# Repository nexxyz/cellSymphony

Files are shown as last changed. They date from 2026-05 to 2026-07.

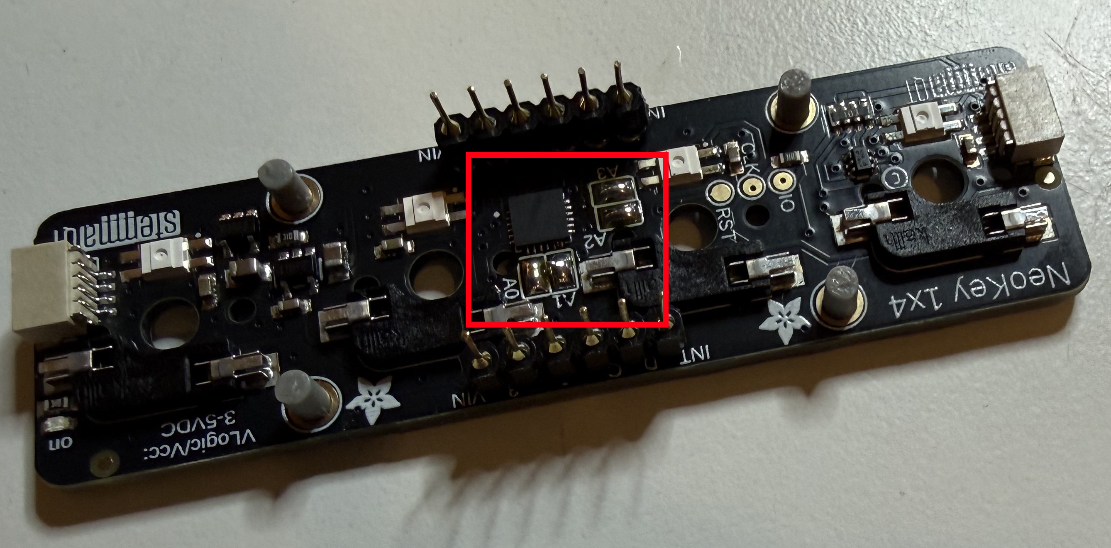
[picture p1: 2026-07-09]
userdocs/hardware/images/assembly/neokey-address-jumpers.jpg

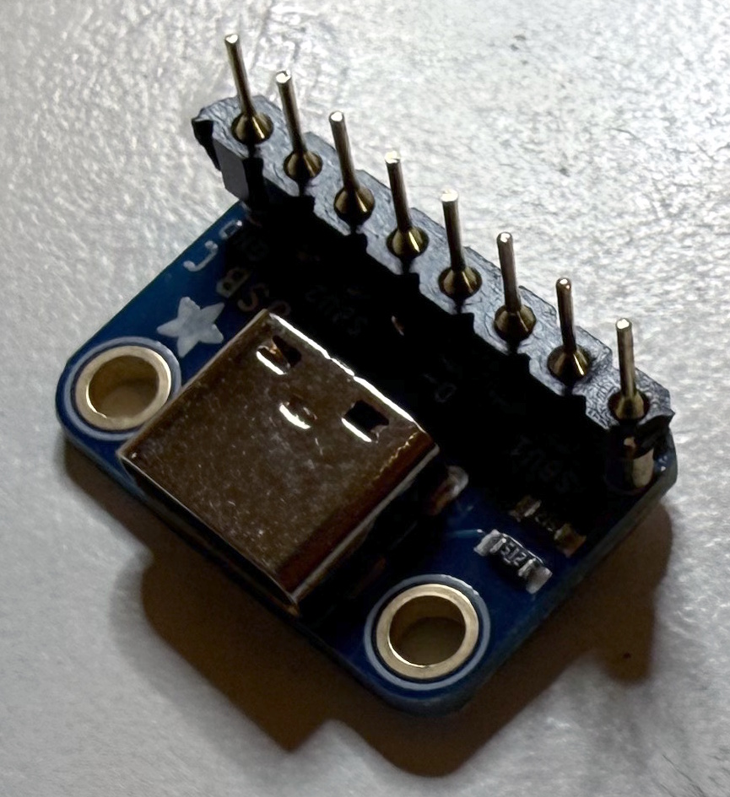
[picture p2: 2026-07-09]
userdocs/hardware/images/assembly/power-breakout.jpg

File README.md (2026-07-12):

# octessera

Octessera turns cellular automata into music you can play.

It is a collection of little algorithmic musical world-bubbles: small systems you set up, nudge, combine, and occasionally interrupt. You are not programming fixed notes on a piano roll. You are giving tiny rule-based worlds something to do, adding a bit of manual sequencing when you want an anchor, and then playing the result in real time.

Start with the user docs: [`userdocs/README.md`](userdocs/README.md).

Create a dynamic, evolving beat in minutes. Let Conway's Life generate a shifting synth backdrop. Add a drumbeat with a classic grid-style sequencer. Make the drums duck the synth out of the way. Play a lead line live. Then jump into Sparks mode and perform with live effects, change trigger probability, and use the XY pad and mixer controls to build something that you and octessera found together.

It is easy to start with, but deep. It rewards exploration and experimentation. Small changes to the grid can become rhythms, melodies, modulation, texture, or surprise.

The intended way of using it is a DIY standalone hardware instrument based on a Raspberry Pi. There is, however, a fully implemented desktop app that serves simulator for building, testing, and playing the same instrument on a computer - but it is also quite usable and effective, if you don't want another piece of gear to clutter your valuable desk real estate.

## What You Can Make

- **Generative synth patterns** from Life, Brain, Ant, Bounce, Raindrops, DLA, and other grid behaviors.
- **Hands-on drum patterns** with a sequencer-style grid and sample slots.
- **Layered arrangements** with up to eight layers/instruments.
- **Live leads** with the Keys behavior.
- **Evolving modulation** where grid motion changes pitch, filter, velocity, effects, and other parameters.
- **Internal synth and sampler sounds**, plus external MIDI output.
- **Performance scenes** with Play pages: mix, pan, trigger probability, XY modulation, and momentary effects.
- **Happy accidents** from systems that keep moving after you set them in motion.

## A Quick Session

1. Pick a layer in **Build** and choose a behavior such as `life`, `brain`, or `raindrops`.
2. Draw or seed a few cells on the grid.
3. Press **Space** to start playback.
4. Go to **Shape** and choose a synth, sampler or even MIDI output for the layer.
5. Add a sequencer layer for drums, have it play a sampler with your preferred drum samples (we even provide a small sample library for you!)
6. Then route the synth through an FX bus with ducking so the beat opens space in the mix.
7. Switch another layer to **Keys** and play a lead line live.
8. Hold **Fn** for navigation and use the right grid column to enter **Play** pages.
9. Perform: mute, pan, change probability, move XY controls, and punch in live effects.

You can treat it like a algorithmic groovebox, a generative sketchpad, or a small experimental performance instrument.

## Controls

The hardware (still under design) uses one clickable main encoder, three clickable aux encoders, four keys with LEDs, an 8x8 grid and a small OLED. The desktop simulator mirrors those controls with keyboard and UI inputs.

| Action | Hardware | Desktop |
|---|---|---|
| Move or change a value | Main encoder turn | Arrow keys |
| Enter, edit, or confirm | Main encoder press | Enter |
| Back or leave edit mode | Back button | Backspace / Esc |
| Play / pause | Space button | Space |
| Emergency stop | Shift + Space | Shift + Space |
| Clear active grid | Shift + Back | Shift + Backspace / Shift + Esc |
| Navigate layers | Fn + left grid column | Ctrl + left grid column |
| Navigate Play pages | Fn + right grid column | Ctrl + right grid column |
| Access alternate aux binding | Fn + aux press | Fn + aux UI control |

The friendly control guide starts at [`userdocs/controls-cheat-sheet.md`](userdocs/controls-cheat-sheet.md). The canonical control/menu spec is [`docs/menu-and-controls-spec.md`](docs/menu-and-controls-spec.md).

## Main Pages

- **Build** — choose the active layer's behavior and edit its grid state.
- **Link** — decide how grid motion becomes notes, velocity, filters, probability, and modulation.
- **Shape** — choose synth, sampler, MIDI, mixer routing, FX buses, and global FX.
- **Play** — perform with mix, pan, trigger probability, XY, and momentary effects.
- **System** — presets, default/factory actions, sound, MIDI, brightness, sleep, and help.

## Build The Hardware

The intended build is a DIY standalone instrument around a custom PCB, Raspberry Pi Zero 2 W, NeoTrellis grid, NeoKey controls, OLED, DAC, and printed enclosure.

Start with the full assembly guide:

- [`userdocs/hardware/assembly-manual.md`](userdocs/hardware/assembly-manual.md) — BOM, PCB ordering, soldering, module setup, Pi flashing, first power-on, and enclosure assembly.

Related references:

1. [`userdocs/hardware/pinout-and-connections.md`](userdocs/hardware/pinout-and-connections.md) — wiring, pin ownership, buses, and hardware source of truth.
2. [`userdocs/hardware/enclosure.md`](userdocs/hardware/enclosure.md) — case, port access, print notes, and power rule.
3. [`docs/menu-and-controls-spec.md`](docs/menu-and-controls-spec.md) — runtime controls, menus, overlays, and display behavior.

## Desktop Simulator

The easiest way to play with this system is to download and launch the portable Windows EXE attached to the official releases.

Releases may also include macOS and Linux desktop simulator builds. Those are currently untested; treat them as experimental until someone has done the boring part and actually run them on those systems.

It allows you try out Octessera without any special hardware.

## Documentation Map

Primary user docs:

- [`userdocs/README.md`](userdocs/README.md): start here for build, bring-up, controls, printable sheets, and references.
- [`userdocs/hardware/assembly-manual.md`](userdocs/hardware/assembly-manual.md): hardware BOM, soldering, first power-on, and enclosure assembly.
- [`userdocs/hardware/pinout-and-connections.md`](userdocs/hardware/pinout-and-connections.md): Pi wiring, bus allocation, logical input mapping, and hardware source of truth.
- [`userdocs/hardware/enclosure.md`](userdocs/hardware/enclosure.md): enclosure ports, power rule, printing notes, and mechanical strategy.
- [`userdocs/controls-cheat-sheet.md`](userdocs/controls-cheat-sheet.md): hardware and simulator controls.
- [`userdocs/behaviors-and-sparks.md`](userdocs/behaviors-and-sparks.md): behavior overview and Sparks page reference.
- [`userdocs/print/quick-reference.pdf`](userdocs/print/quick-reference.pdf): two-page printable controls, behaviors, Sparks, and signal-flow sheet.

Canonical specs:

- [`docs/menu-and-controls-spec.md`](docs/menu-and-controls-spec.md): authoritative controls, menu structure, overlays, persistence, and display behavior.
- [`docs/menu-tree-spec.md`](docs/menu-tree-spec.md): canonical menu tree.

Secondary contributor docs:

- [`docs/runtime-boundaries.md`](docs/runtime-boundaries.md): crate/host responsibilities and dependency boundaries.
- [`docs/development-workflows.md`](docs/development-workflows.md): current development, build, verification, and capability-generation commands.
- [`docs/engineering-quality-requirements.md`](docs/engineering-quality-requirements.md): current quality gates and definition of done.
- [`docs/open-work.md`](docs/open-work.md): current actionable work only.

## Samples

Repository sample content is sourced from the [Stargate sample pack](https://github.com/stargatedaw/stargate-sample-pack).

## Hardware model attributions

The standoff STL models in `release-artifacts/enclosure/` are based on [Stackable PCB Standoff by theduckom](https://www.printables.com/model/163087-stackable-pcb-standoff), licensed under [Creative Commons Attribution 4.0 International](https://creativecommons.org/licenses/by/4.0/).

AI assistance was used during the creation of Octessera.

## License

Copyright (c) 2026 nexxyz.

Free for personal/non-commercial use: you may use, copy, modify, and build this software for personal purposes.

Commercial use or selling hardware devices requires prior written permission.

To request permission, contact: https://github.com/nexxyz

See [LICENSE](LICENSE) for full terms.

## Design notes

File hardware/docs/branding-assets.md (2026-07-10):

# Branding assets

This project uses the octessera mark and wordmark across hardware docs, PCB silkscreen, enclosure CAD, Pi splash screens, Raspberry Pi Imager metadata, and the desktop hardware simulator icon.

## Source assets

- `assets/octessera-mark.svg`: vector mark source.
- `assets/octessera-wordmark.svg`: grid-native vector wordmark source.
- `tools/assets/generate_pi_logo_pngs.py`: generates Pi splash and Imager PNG assets.
- `apps/desktop/src-tauri/icons/`: generated desktop simulator icon assets.
- `hardware/enclosure/branding_marking_cadquery.py`: converts the SVG mark and wordmark into CadQuery solids.
- `hardware/pcb/octessera.kicad_pcb`: contains the PCB silkscreen branding geometry.

Keep the SVGs as the source of truth. Do not hand-edit generated PNGs, STL files, STEP files, or 3MF files as source.

## Fill rules

The wordmark SVG is built from filled block paths. When rasterizing or converting it, use union-fill semantics: a point is filled if it is inside any wordmark path.

Do not use even-odd/parity fill for the current wordmark. Even-odd fill can cancel overlapping or touching block paths and can remove letter joins.

If a future wordmark uses compound paths with holes, update the source model explicitly instead of silently changing all converters to parity fill.

## Pi PNGs and initramfs

Run this after changing the mark or wordmark SVG:

```powershell
python tools/assets/generate_pi_logo_pngs.py
```

Generated PNGs:

- `assets/octessera-pi-manifest.png`: Raspberry Pi Imager icon.
- `assets/octessera-app-large.png`: desktop app icon source.
- `assets/octessera-pi-booting.png`: Pi boot splash.
- `assets/octessera-pi-sleeping.png`: sleep splash mark.
- `assets/octessera-pi-shutdown.png`: shutdown splash mark.
- `apps/desktop/src-tauri/icons/icon.png`: desktop hardware simulator icon.
- `apps/desktop/src-tauri/icons/icon.ico`: Windows desktop hardware simulator icon.

The Pi build embeds the PNGs through `apps/pi-zero/build.rs`, which writes RGB565 splash assets into Cargo `OUT_DIR`. Rebuild the Pi binary or Pi image/initramfs after changing these PNGs.

## Enclosure branding

The enclosure top uses `hardware/enclosure/branding_marking_cadquery.py`.

- STEP/STL exports keep branding as raised separate solids.
- The branded multicolor 3MF keeps the branding flush with the top surface and assigns it to extruder 2.

Use the branded top wrapper after changing branding or top enclosure CAD:

```powershell
powershell -NoProfile -ExecutionPolicy Bypass -File hardware/enclosure/generate_branded_top_artifacts_checked.ps1
```

Expected outputs:

- `release-artifacts/enclosure/step/case_top_two_level_cadquery.step`
- `release-artifacts/enclosure/stl/case_top_two_level_cadquery.stl`
- `release-artifacts/enclosure/3mf-multicolor/case_top_two_level_multicolor.3mf`
- ignored review images under `hardware/enclosure/review/`

Do not restore the old unbranded top 3MF; the top 3MF should be multicolor only.

## PCB branding

The PCB silkscreen branding lives in `hardware/pcb/octessera.kicad_pcb` on `F.SilkS`.

Use `assets/octessera-mark.svg` and `assets/octessera-wordmark.svg` as the basis when regenerating it. Preserve the manually tuned placement unless intentionally changing the PCB layout.

After editing generated PCB graphic primitives, check:

- parentheses are balanced;
- UUIDs are unique;
- no local absolute paths are introduced;
- `by nexxyz` remains present if the layout still uses the byline.

## Cleanup checklist

Before committing branding or hardware artifact changes, check:

- no local Windows absolute paths in tracked project files;
- KiCad libraries live under `hardware/pcb/kicad-libs/`;
- review images are under ignored `hardware/enclosure/review/`, not `release-artifacts/`;
- the old unbranded top 3MF is absent;
- generated Python `__pycache__/` directories are not staged;
- `git diff --check` passes.

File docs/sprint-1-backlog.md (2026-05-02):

# Sprint 1 Backlog (Foundation + Simulator Skeleton)

## Sprint Goal

Establish the modular foundation and desktop simulator skeleton with strict hardware-style controls, while keeping platform/navigation/transport decoupled from generative behavior logic.

## Deliverables

- Monorepo skeleton and package boundaries
- Device contracts and event schemas
- Platform core scaffolding (navigation + transport interfaces)
- Behavior API and Game of Life behavior module scaffold
- Desktop simulator shell with required keyboard/control mappings
- CI workflow scaffold and quality gates in repository

## Backlog Items

### 1) Repository Skeleton

Priority: High

Tasks:

- Create directories:
  - `apps/desktop`
  - `packages/device-contracts`
  - `packages/platform-core`
  - `packages/behavior-api`
  - `packages/behaviors-life`
  - `packages/musical-events`
  - `crates/realtime-engine`
- Add top-level workspace manifests (`pnpm-workspace.yaml`, root `package.json`).
- Add base TypeScript config and shared lint/format config.

Acceptance:

- Workspace install and base scripts resolve cleanly.

### 2) Device Contract Definitions

Priority: High

Tasks:

- Add TS types for device input:
  - `EncoderTurn`, `EncoderPress`, `ButtonA`, `ButtonS`, `GridPress`
- Add TS types for render/output models:
  - `DisplayFrame`, `LedMatrixFrame`, `TransportFrame`, `EngineFrame`
- Add serialization-safe schemas (zod or equivalent) for project storage boundaries.

Acceptance:

- Contract package builds and exports typed public API.

### 3) Platform Core Scaffolding

Priority: High

Tasks:

- Implement navigation state machine skeleton:
  - page selection
  - focus/edit mode
  - Back/Cancel handling (Button A)
- Implement transport state skeleton:
  - play/stop toggle (Button S)
  - bpm value storage
  - clock interface abstraction (implementation deferred)
- Define behavior host interface:
  - register active behavior
  - route input/tick
  - collect `MusicalEvent` output

Acceptance:

- Platform core handles controls without referencing any specific behavior internals.

### 4) Behavior API + Game of Life Module Scaffold

Priority: High

Tasks:

- Create behavior API package with interface/lifecycle contracts.
- Create `behaviors-life` package implementing the interface with placeholders.
- Add deterministic state/tick scaffolding and serialization stubs.

Acceptance:

- Platform can mount behavior module via API without direct imports into UI layer.

### 5) Desktop Simulator UI Skeleton

Priority: High

Tasks:

- Initialize Tauri + React app shell.
- Build required UI elements:
  - screen panel
  - encoder control widget
  - A/S button widgets
  - clickable 8x8 matrix
- Implement keyboard mapping:
  - Left/Right -> encoder delta
  - Enter -> encoder press
  - A/S -> dedicated buttons
- Route events through contract bus only.

Acceptance:

- Visible simulator shell operates with required mappings and emits typed input events.

### 6) CI + Quality Baseline Integration

Priority: High

Tasks:

- Add CI workflow (`.github/workflows/ci.yml`) and adjust scripts as packages land.
- Add minimal test harness in TS packages.
- Add rust crate skeleton with passing fmt/clippy/test commands.

Acceptance:

- CI passes for scaffold state on PR.

## Suggested Task Order

1. Repository skeleton
2. Device contracts
3. Platform core scaffold
4. Behavior API + life scaffold
5. Desktop simulator skeleton
6. CI script wiring and test harness

## Out of Scope for Sprint 1

- Full CA musical mapping logic
- MIDI runtime implementation
- Internal synth DSP implementation
- FLAC import conversion pipeline implementation
- ROMpler playback engine implementation

## Risks and Mitigation

- Risk: accidental coupling between UI and behavior internals.
  - Mitigation: enforce contract-only data flow in code reviews/tests.
- Risk: CI workflow mismatch before scripts exist.
  - Mitigation: include temporary no-op or scaffold scripts and tighten quickly.

## Definition of Done (Sprint 1)

- All Sprint 1 deliverables are merged with passing CI.
- Control mappings match the hardware-first specification.
- Platform/navigation/transport code remains behavior-agnostic.
- A behavior module can be swapped without touching platform core interfaces.

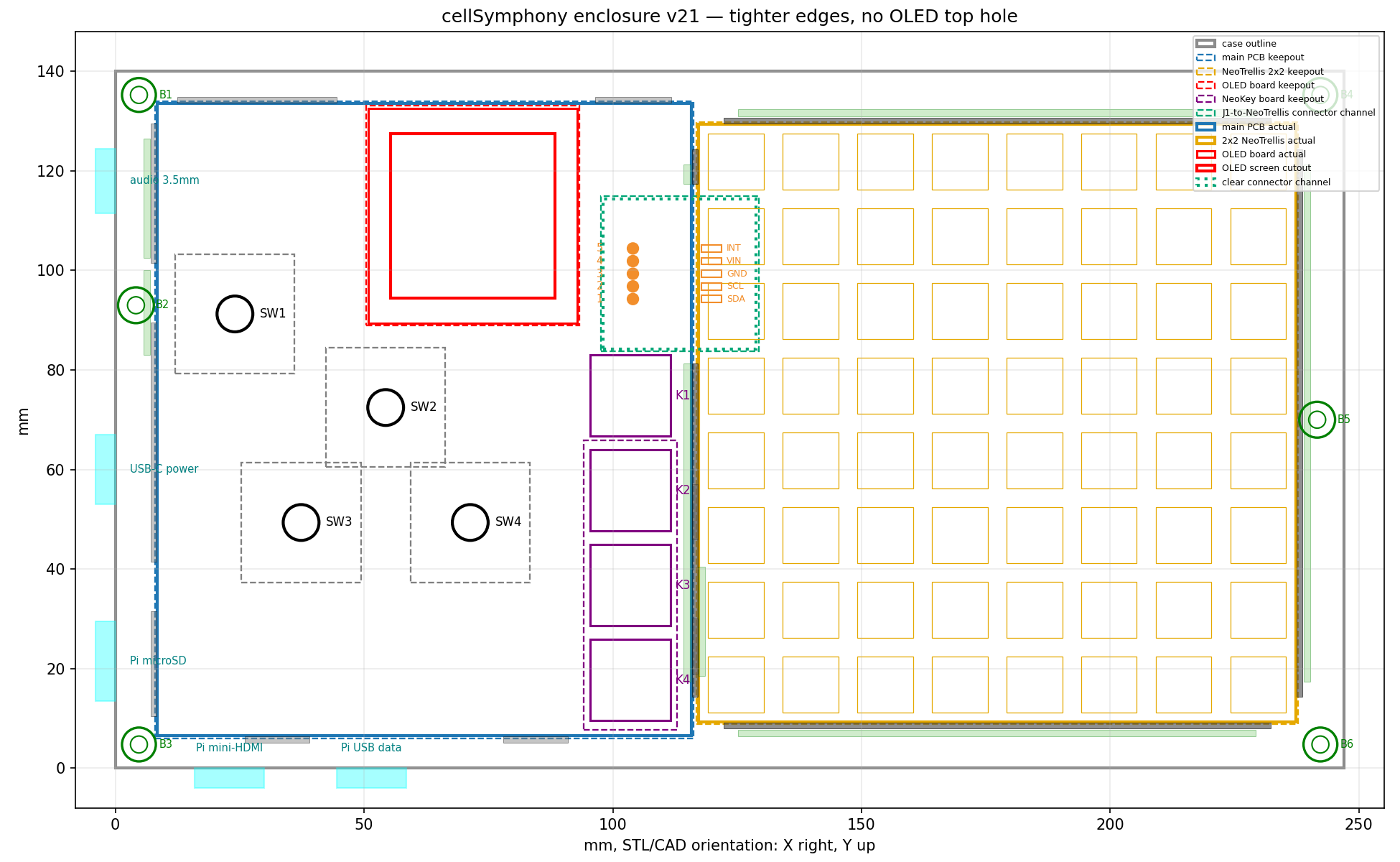
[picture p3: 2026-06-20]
hardware/enclosure/layout.png

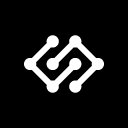
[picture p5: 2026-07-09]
assets/octessera-pi-shutdown.png

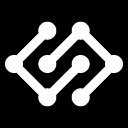
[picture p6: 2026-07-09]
assets/octessera-app-large.png

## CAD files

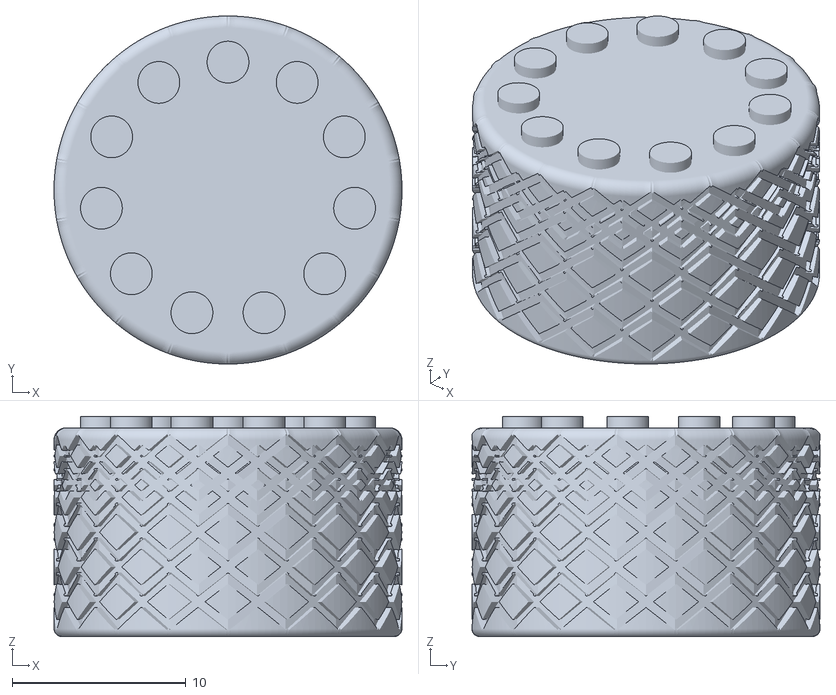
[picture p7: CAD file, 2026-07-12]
release-artifacts/enclosure/stl/encoder_cap_main_knurled_dots.stl
20.0 x 20.0 x 12.6

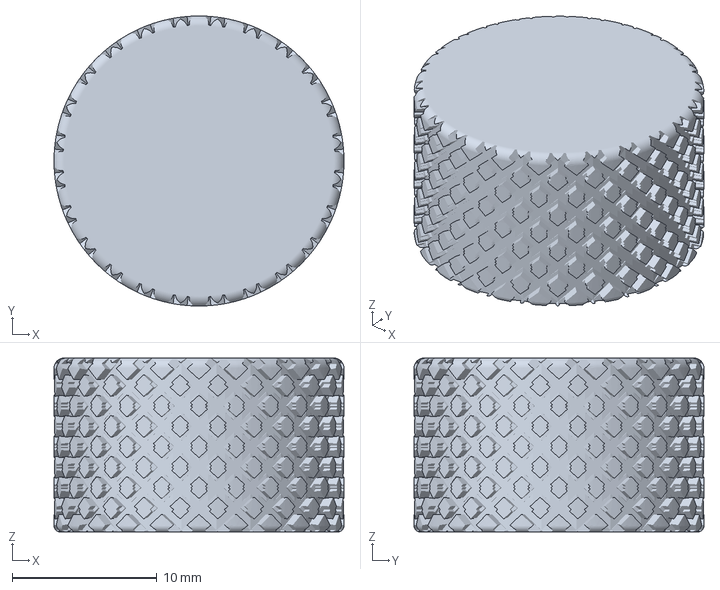
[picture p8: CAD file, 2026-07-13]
release-artifacts/enclosure/3mf-multicolor/encoder_cap_main_knurled_dots_multicolor_flush.3mf
20.0 x 20.0 x 12.0 mm

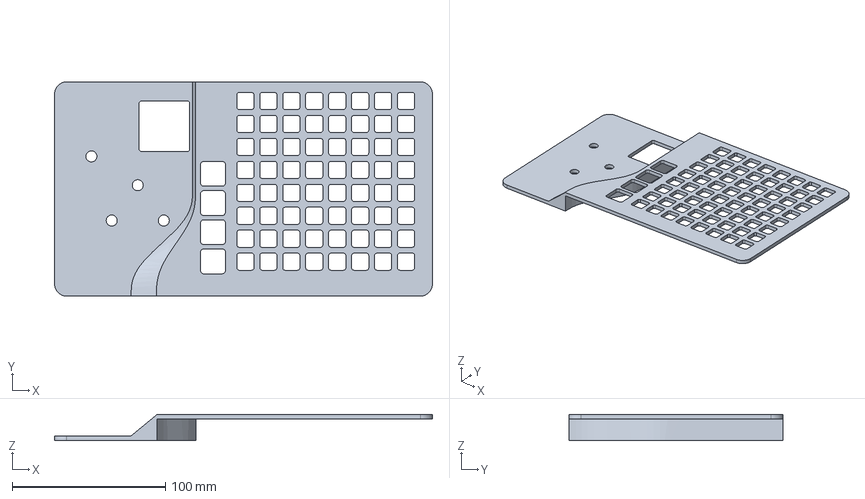
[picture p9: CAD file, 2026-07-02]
hardware/enclosure/case_top_two_level_cadquery.step
247.0 x 140.0 x 17.0 mm

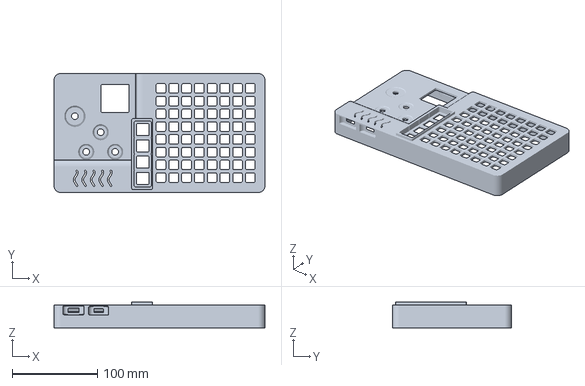
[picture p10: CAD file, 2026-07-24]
release-artifacts/enclosure/3mf-multicolor/case_top_two_level_multicolor.3mf
248.0 x 140.0 x 30.0 mm

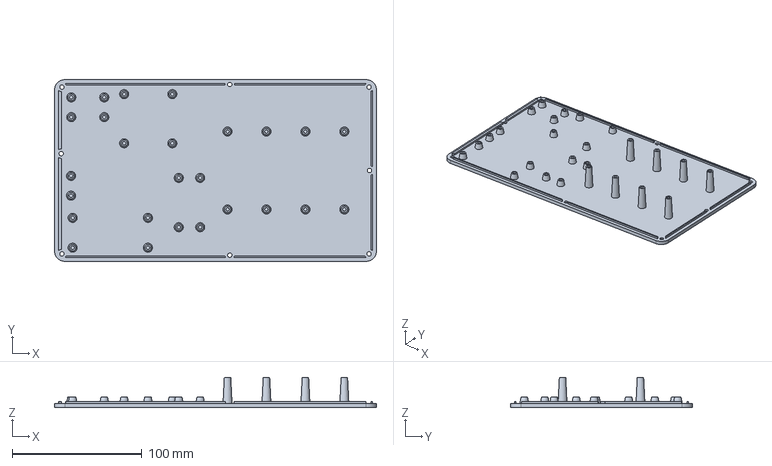
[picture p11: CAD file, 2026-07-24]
release-artifacts/enclosure/step/case_bottom_plate_cadquery.step
248.0 x 140.0 x 23.2 mm

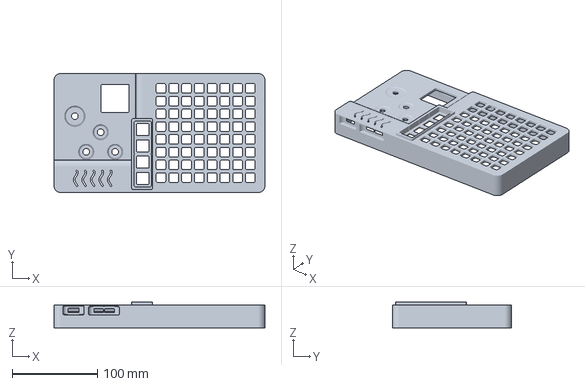
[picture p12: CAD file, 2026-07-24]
release-artifacts/enclosure/3mf-multicolor/case_top_two_level_orange_pi_multicolor.3mf
248.0 x 140.0 x 30.0 mm

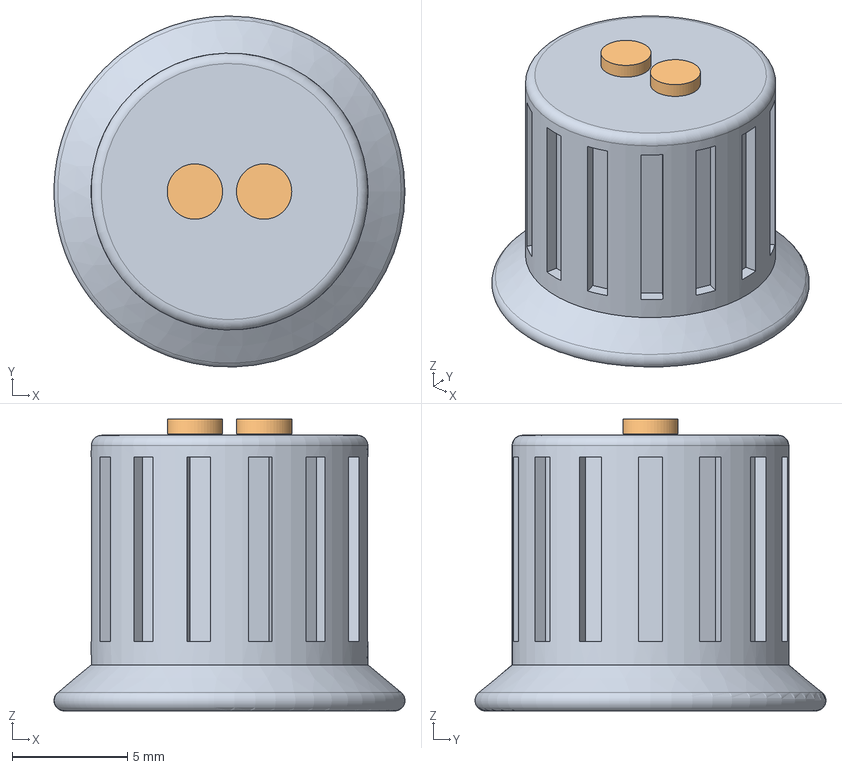
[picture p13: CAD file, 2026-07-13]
release-artifacts/enclosure/step/encoder_cap_aux2_ribbed_dots.step
15.2 x 15.2 x 12.7 mm

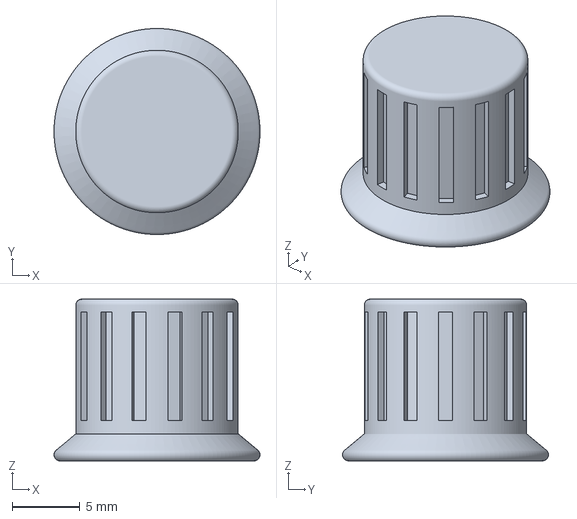
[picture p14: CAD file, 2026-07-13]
release-artifacts/enclosure/3mf-multicolor/encoder_cap_aux1_ribbed_dot_multicolor_flush.3mf
15.2 x 15.2 x 11.9 mm

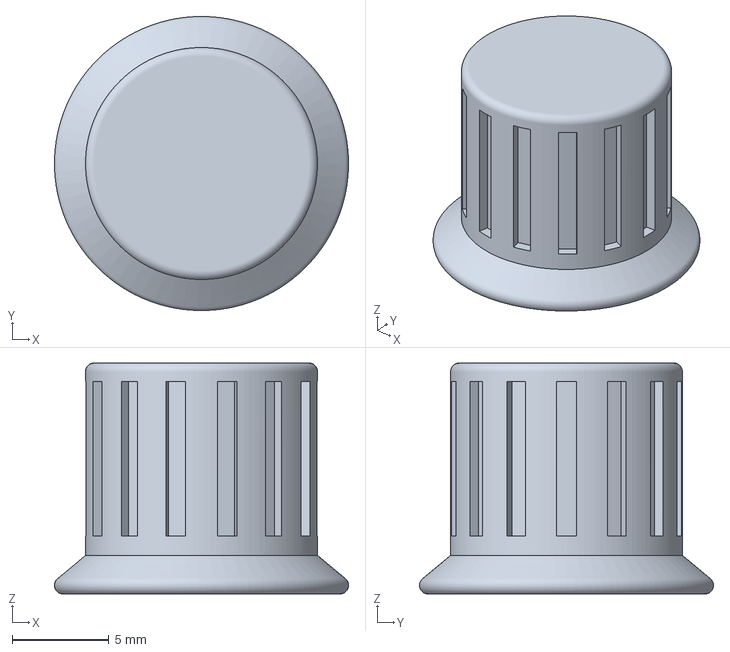
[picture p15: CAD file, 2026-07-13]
release-artifacts/enclosure/3mf-multicolor/encoder_cap_aux3_ribbed_dots_multicolor_flush.3mf
15.2 x 15.2 x 11.9 mm

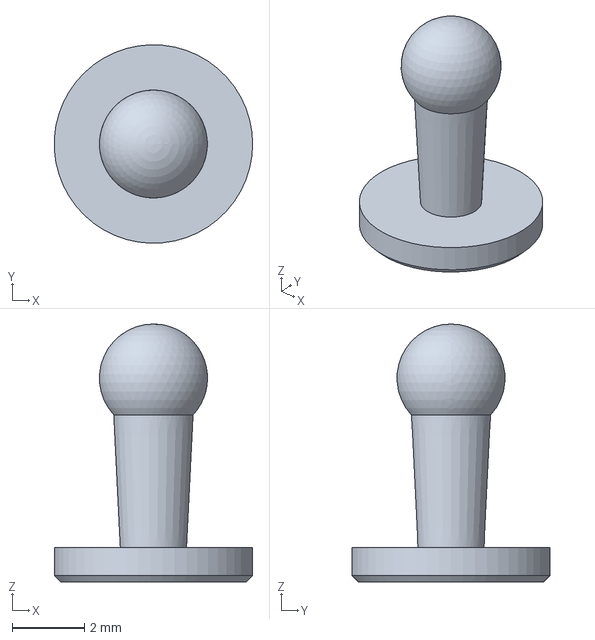
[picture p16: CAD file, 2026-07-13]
release-artifacts/enclosure/step/friction_insert_spreading_pin_headed.step
5.49 x 5.50 x 7.15 mm

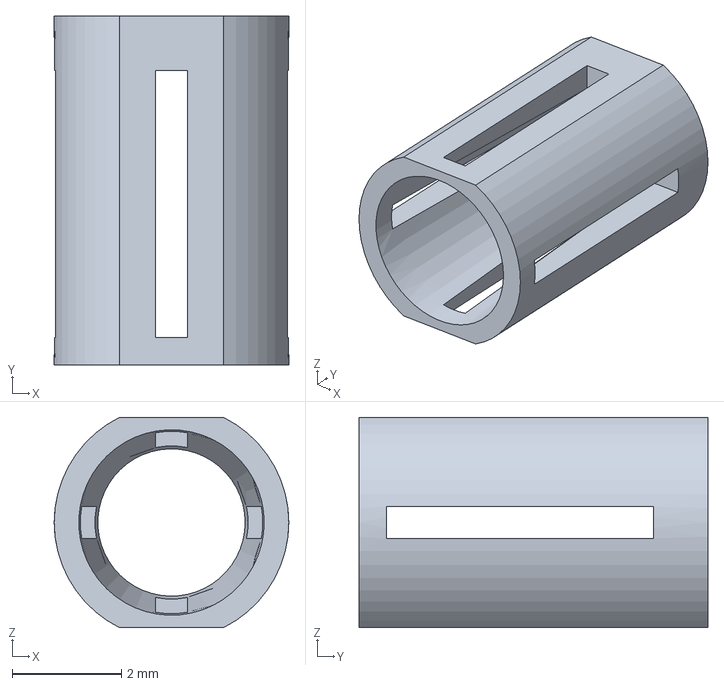
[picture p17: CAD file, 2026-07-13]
release-artifacts/enclosure/step/friction_insert_expanding_plug_flat_sides.step
4.30 x 6.40 x 3.85 mm

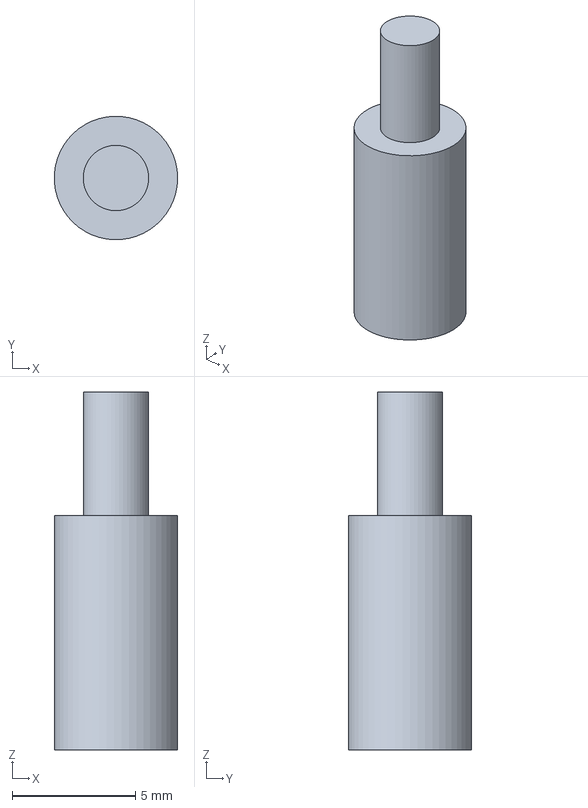
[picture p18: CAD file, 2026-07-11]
release-artifacts/enclosure/step/standoff_pillar_9_5mm.step
5.00 x 5.00 x 14.5 mm

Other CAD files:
release-artifacts/enclosure/stl/case_top_two_level_cadquery_orange_pi.stl
release-artifacts/enclosure/stl/case_top_two_level_cadquery.stl
release-artifacts/enclosure/step/encoder_cap_aux1_ribbed_dot.step
release-artifacts/enclosure/step/encoder_cap_aux3_ribbed_dots.step
release-artifacts/enclosure/3mf-multicolor/encoder_cap_aux2_ribbed_dots_multicolor_flush.3mf
release-artifacts/enclosure/3mf-multicolor/friction_insert_expanding_plug_flat_sides.3mf
release-artifacts/enclosure/3mf-multicolor/case_bottom_plate_cadquery.3mf
release-artifacts/enclosure/3mf-multicolor/friction_insert_spreading_pin_headed.3mf
release-artifacts/enclosure/3mf-multicolor/mx_keycap_back_multicolor_flush.3mf
release-artifacts/enclosure/3mf-multicolor/mx_keycap_fn_layer_multicolor_flush.3mf
release-artifacts/enclosure/3mf-multicolor/mx_keycap_play_multicolor_flush.3mf
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

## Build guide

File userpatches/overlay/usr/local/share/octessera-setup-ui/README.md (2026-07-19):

# Octessera setup portal

Static UI for the first-boot wifi-connect captive portal.

## Backend calls

- `GET /networks`
- `POST /stage`
- `POST /connect`

## `/stage` request body

Send JSON to `http://192.168.42.1:8080/stage` with these exact fields:

```json
{
  "sshMode": "none",
  "sshPublicKey": "",
  "sshPassword": "",
  "sshPasswordConfirm": "",
  "hostname": "",
  "wifiCountry": "US"
}
```

`sshMode` must be one of `none`, `key`, or `password`.

## `/connect` request body

Send form-urlencoded fields:

- `ssid`
- `identity`
- `passphrase`

`identity` may be blank.

## Behavior

- Call `/stage` before `/connect`.
- Keep all form state in memory only.
- Do not rely on external assets, fonts, or storage.

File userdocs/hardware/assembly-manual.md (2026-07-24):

# octessera hardware assembly manual

This guide builds the standalone Octessera instrument: PCB, soldered controls, plug-in modules, NeoTrellis grid, Raspberry Pi image, and enclosure.

The hardware is still being fit-tested. Check the current enclosure files before ordering printed parts, and do the slow fit checks before you close the box. Tiny clearances are where instruments learn humility.

If you are new here, start with the friendlier map in [`../README.md`](../README.md), then come back with a soldering iron and snacks.

## Source files

- Gerbers for PCB fabrication: [`../../release-artifacts/pcb/gerber/gerber.zip`](../../release-artifacts/pcb/gerber/gerber.zip)
- Schematic: [`../../hardware/pcb/octessera.kicad_sch`](../../hardware/pcb/octessera.kicad_sch)
- PCB layout: [`../../hardware/pcb/octessera.kicad_pcb`](../../hardware/pcb/octessera.kicad_pcb)
- Wiring reference: [`pinout-and-connections.md`](pinout-and-connections.md)
- Enclosure reference: [`enclosure.md`](enclosure.md)
- User docs home: [`../README.md`](../README.md)

## BOM

### PCB and electronics

| Qty | Item | Exact/current part | Notes |
|---:|---|---|---|
| 1 | Custom PCB | Fabricate from [`../../release-artifacts/pcb/gerber/gerber.zip`](../../release-artifacts/pcb/gerber/gerber.zip) | Order as a two-layer PCB unless the Gerber notes say otherwise. |
| 4 | NeoTrellis 4x4 driver PCB | [Adafruit `3954`](https://www.adafruit.com/product/3954), Mouser `485-3954` | Forms the 8x8 grid. |
| 4 | Silicone 4x4 keypad | [Adafruit `1611`](https://www.adafruit.com/product/1611), Mouser `485-1611` | One per NeoTrellis board. |
| 1 | NeoKey 1x4 QT | [Adafruit `4980`](https://www.adafruit.com/product/4980), Mouser `485-4980` | Holds the four Cherry MX keys. |
| 1 | Raspberry Pi Zero 2 W with header | [Raspberry Pi Zero 2 W](https://www.raspberrypi.com/products/raspberry-pi-zero-2-w/), Mouser `358-SC0721`, Raspberry Pi `SC0721` | Use the headered version. |
| 1 | SSD1351 OLED breakout with microSD holder | [Adafruit `1431`](https://www.adafruit.com/product/1431), Mouser `485-1431` | SPI display. |
| 1 | PCM5102 I2S DAC | [Adafruit `6250`](https://www.adafruit.com/product/6250), Mouser `485-6250` | Line/headphone output path. |
| 1 | USB-C power breakout | [Adafruit `4090`](https://www.adafruit.com/product/4090), Mouser `485-4090` | Power the device here, not through the Pi. |
| 4 | Horizontal rotary encoder with switch | [RS `781-6811`](https://at.rs-online.com/web/p/mechanische-drehgeber/7816811), Bourns `PEC12R-4225F-S0024` | The PCB uses four encoders. |
| 1 | Polarized capacitor | [`470uF`, 16V, radial, about 8x12mm](https://de.aliexpress.com/item/1005010415990713.html) | PCB footprint: `CP_Radial_D8.0mm_P3.50mm`. Any equivalent 470uF polarized radial capacitor with 3.5mm lead pitch and >5V rating is fine. |
| 1 | 1x5 right-angle male header, 2.54mm pitch | Any standard breakaway right-angle male pin header | Cut to 5 pins for the NeoTrellis connector on the PCB. The PCB connector indicator still applies; no PCB/Gerber change is needed. |
| 1 | 5-wire female-to-female Dupont cable, about 10cm | Any 2.54mm female-to-female jumper cable set | Use five adjacent leads to connect the NeoTrellis array to the PCB. |
| 25 pins | Straight male pin header, 2.54mm pitch | Any standard breakaway male pin header strip | Use 20 pins to link the four NeoTrellis boards together, plus 5 pins for the external connection point on the upper-left NeoTrellis board. |
| several | Low-profile female header/socket strips, 2.54mm pitch | [Round-pin 2.54mm header/socket strip](https://de.aliexpress.com/item/1005006673257121.html) or [round-pin 2.54mm header/socket strip](https://de.aliexpress.com/item/4001122376295.html) | Cut to length for Pi, OLED, DAC, power breakout, and other plug-in modules. Confirm the socket height before ordering. |
| 4 | Cherry MX-compatible key switches | [Cherry MX Black switches](https://www.amazon.de/-/en/CHERRY-Mechanical-Keyboard-Switches-without/dp/B0CBS4HJJR?th=1), or any MX-compatible switch | Install into the NeoKey after bring-up. |
| 1 | MicroSD card for Raspberry Pi | 16GB or larger recommended | Flash the release image. |
| 1 | USB-C power supply | Regulated 5V supply, 3A minimum; 4A recommended for extra LED headroom | Connect only to the USB-C breakout. A 2A supply is likely marginal once the Pi and LEDs are running together. |
| 1 | Data-only USB cable or power-isolating USB adapter | Optional, for Pi USB data/gadget use | Needed if you want the Pi data port connected to a host without back-powering the device from that host. Software cannot block USB 5V for you. |
| 1 | Audio cable/headphones/speaker | 3.5mm audio | Used for test and operation. |

### 3D printed and mechanical parts

The enclosure is printable, including the dowel/standoff and top-pin system that holds the boards and case together. Screws and heat-set inserts are still recommended for the tidiest, most travel-safe build, but they are optional rather than mandatory.

Note that there are a lot of parts that fit snugly into each other and into the components' mount holes, with rather tight tolerances. Make sure your printer is well calibrated, or test things out with partial prints ahead of time and scale e.g. pins and standoffs accordingly on X/Y axis to make them fit the pillars.

| Qty | Item | File/spec | Notes |
|---:|---|---|---|
| 1 | Enclosure top | `../../release-artifacts/enclosure/stl/case_top_two_level_cadquery.stl` | Generated from CadQuery. STEP file is also checked in. |
| 1 | Enclosure bottom | `../../release-artifacts/enclosure/stl/case_bottom_plate_cadquery.stl` | Current bottom plate with guide walls and screw holes. |
| 1 | Main encoder knob | Print `../../release-artifacts/enclosure/stl/encoder_cap_main_knurled_dots.stl` or use `../../release-artifacts/enclosure/3mf-multicolor/encoder_cap_main_knurled_dots_multicolor_flush.3mf` | Main encoder cap. Printed version uses the dot-ring marking. |
| 3 | Aux encoder knobs | Print `../../release-artifacts/enclosure/stl/encoder_cap_aux*_ribbed_dot*.stl` or use matching `../../release-artifacts/enclosure/3mf-multicolor/encoder_cap_aux*_multicolor_flush.3mf` | Aux 1/2/3 caps. Printed versions use one, two, and three dots. |
| 4 | MX keycaps | Print `../../release-artifacts/enclosure/stl/mx_keycap_*.stl`, use matching `../../release-artifacts/enclosure/3mf-multicolor/mx_keycap_*_multicolor_flush.3mf`, or use any MX-stem keycap | Four NeoKey caps: back, play, shift, and function/layer. Transparent filament for the cap body (so the color LEDs of the NeoKey can shine through) and dark filament for the symbols works well, either with a filament swap for the last layers or multi-material printing. |
| 8 | 9.5mm standoff pillar | Print `../../release-artifacts/enclosure/stl/standoff_pillar_9_5mm.stl` and matching `../../release-artifacts/enclosure/3mf-multicolor/standoff_pillar_9_5mm.3mf`, or use compatible purchased stackable PCB standoffs | Use for the OLED and audio/DAC board support locations. |
| 10 | 10mm standoff pillar | Print `../../release-artifacts/enclosure/stl/standoff_pillar_10mm.stl` and matching `../../release-artifacts/enclosure/3mf-multicolor/standoff_pillar_10mm.3mf`, or use compatible purchased stackable PCB standoffs | Use for the Raspberry Pi, power breakout, and NeoKey support locations. NeoTrellis array pins go straight into the bottom's integrated pillars, so they do not need separate standoff pillars. |
| 26 | Standoff top pin | Print `../../release-artifacts/enclosure/stl/standoff_top_pin_thin_base.stl` and matching `../../release-artifacts/enclosure/3mf-multicolor/standoff_top_pin_thin_base.3mf`, or use compatible purchased stackable PCB standoff pins | 4 Pi + 4 audio/DAC + 4 OLED/screen + 4 NeoKey + 2 power + 8 NeoTrellis array pins = 26 total. |
| 8 | Heat-set insert | M3x6x5 heat-set insert, such as the M3 size in this [heat-set insert kit](https://de.aliexpress.com/item/1005012199553197.html) | Recommended, but optional if the printed dowel/top-pin system grips well enough. Insert from the underside of the top. The smooth lead-in side should locate in the `4.6mm` pilot hole before heat-setting. |
| 8 | Screws | M3x8 socket-head cap screw, DIN 912 / ISO 4762 style | Recommended, but optional if the printed dowel/top-pin system grips well enough. Installed from the bottom. Use a head diameter no larger than `6.4mm` so it fits the counterbores. |
| 8 | Rubber feet or screw-hole plugs | Small adhesive feet | Optional, covers bottom screw holes and prevents sliding. |

Standoff STL attribution and purchase/source reference: the standoff models are based on [Stackable PCB Standoff by theduckom](https://www.printables.com/model/163087-stackable-pcb-standoff), licensed under [Creative Commons Attribution 4.0 International](https://creativecommons.org/licenses/by/4.0/).

### Tools and consumables

- Soldering iron and solder.
- Flush cutters.
- Optional: small screwdriver for bottom screws.
- Optional: heat-set insert tool.
- Optional: pliers for gently tuning top-pin fit.
- Multimeter.
- Raspberry Pi Imager.
- Optional: continuity tester, tweezers, helping hands, and magnifier.

## Before soldering

1. Inspect the PCB for visible manufacturing defects.
2. Confirm the PCB matches the current Gerber zip.
3. Sort sockets, headers, and modules before soldering.
4. Keep every module oriented the same way it will sit in the enclosure.
5. Mark the correct side of every module before soldering headers.

Headers on the wrong side are difficult to fix. Check the silkscreen, enclosure orientation, and module footprint before soldering. Best double-check every header before soldering it: the correct side matters for the PCB sockets, Pi, OLED, DAC/audio breakout, power breakout, NeoKey, and NeoTrellis connector.

Reference photos:

- [Soldered PCB overview](images/assembly/soldered-pcb.jpg)
- [Raspberry Pi Zero 2 W header side](images/assembly/pi-zero-2w.jpg)
- [OLED header side](images/assembly/oled.jpg)
- [Audio breakout header side](images/assembly/audio-breakout.jpg)
- [Power breakout header side](images/assembly/power-breakout.jpg)

## Solder the main PCB

Solder low-profile sockets and headers first. They define module height and alignment.

1. Solder the low-profile sockets for the Raspberry Pi, OLED, DAC, USB-C power breakout, and any other socketed modules.
2. Solder the 1x5 right-angle male header for the NeoTrellis connector.
3. Solder `C1`, the `470uF` polarized capacitor. Match polarity to the PCB markings.
4. Solder the four rotary encoders into `SW1` through `SW4`.

You can leave the capacitor legs a little longer than usual so the capacitor can bend sideways if you need to save vertical space. Keep polarity correct and make sure the legs cannot short against nearby pads or metal parts.

The horizontal NeoTrellis connector can be a tight fit near the case pillar that supports the NeoTrellis. Keep the right-angle header aimed toward the NeoTrellis cable path, and check the connector indicator on the PCB before soldering.

Do not install plug-in modules yet.

## Build the NeoTrellis array

The four NeoTrellis boards form one 8x8 grid.

1. Arrange the boards as viewed from the play surface:
   - upper left
   - upper right
   - lower left
   - lower right
2. Pretend they are already soldered together and turn them around like they are one plane already (meaning left and right switch places).
3. Solder the boards together with 20 straight male header pins between adjacent edges.
4. Add 5 straight male header pins as the external connection point on the left side of the upper-left NeoTrellis board.
5. Set the NeoTrellis addresses (now that they are switched! This is looking at them from the bottom!):

   | Position | Jumpers | Address |
   |---|---|---:|
   | upper left | A0 | `0x2F` |
   | upper right | none | `0x2E` |
   | lower left | A0 + A1 | `0x31` |
   | lower right | A1 | `0x30` |

Use the reference photos to confirm the soldered address jumper pads:

- [NeoTrellis address jumper pads](images/assembly/neotrellis-address-jumpers.jpg). Note that there is solder on A1 on the upper left in the picture, but it is not shorted. I shorted it by mistake, separated the pads but and then not clean it up completely. So don't get confused by those drops of solder.

5. Set the NeoKey address by soldering A0, A1, A2, and A3. The expected address is `0x3F`.

- [NeoKey address jumper pads](images/assembly/neokey-address-jumpers.jpg)

The NeoKey and NeoTrellis connector are the two parts that are easiest to plug in backwards. Double-check their orientation before powering the device. The simplest check is that `INT` should always be on the south side.

## Flash the Raspberry Pi image

1. Download the latest release image from the project releases. It is named like:

   ```text
   octessera-<version>-raspberry-pi-zero-2w.img.zip
   ```

2. Flash it to the Pi microSD card with Raspberry Pi Imager.
3. Configure WiFi, SSH, hostname, and locale in Raspberry Pi Imager if you need network access.
4. Insert the microSD card into the Raspberry Pi.

You can flash the downloaded `.img.zip` directly with Raspberry Pi Imager by choosing **Use custom** and selecting the ZIP. You do not need to extract the ZIP first.

The release also includes Raspberry Pi Imager metadata in two places:

- inside the image ZIP as `os_list.rpi-imager-manifest`;
- next to the image ZIP as `octessera-<version>-raspberry-pi-zero-2w.rpi-imager-manifest`.

If you want octessera to appear as a custom OS entry in Raspberry Pi Imager, use the standalone `.rpi-imager-manifest` release asset as Imager's custom repository manifest. Loading the manifest/custom image this way lets Raspberry Pi Imager configure locale, WiFi, SSH, hostname, and user settings before flashing.

In Raspberry Pi Imager, open **App Options**, press **Edit** next to **Content Repository**, then choose one of these options:

- **Use custom file**: select the downloaded `.rpi-imager-manifest` file.
- **Use custom URL**: paste the manifest URL from the GitHub release.

Then press **Apply and Restart**. After Imager restarts, the octessera image will show up in the **OS** list after you have selected your device type.

Reference screenshots:

- [Raspberry Pi Imager options](images/assembly/rpi-imager-options.png)
- [Content Repository setting](images/assembly/rpi-content-repository.png)
- [Custom repository source](images/assembly/rpi-repository-source.png)

You can also start Imager with the manifest URL from the command line, for example:

```powershell
rpi-imager --repo "https://github.com/nexxyz/octessera/releases/download/v<version>/octessera-<version>-raspberry-pi-zero-2w.rpi-imager-manifest"
```

Use the actual release tag and version from the release page. The embedded manifest inside the ZIP is for packaged metadata; do not extract the ZIP just to load the manifest.

For manual Pi setup and developer deploy/update workflows, see [`../../docs/development-workflows.md`](../../docs/development-workflows.md).

## First electrical assembly

1. Insert the Raspberry Pi, OLED, DAC, USB-C power breakout, and NeoKey into their sockets.
2. Connect the NeoTrellis array to the PCB with the 5-wire female-to-female Dupont cable.
3. Install the Cherry MX switches into the NeoKey.
4. Add the four keycaps. Use either printed keycaps from `release-artifacts/enclosure/stl/` or purchased MX-stem keycaps. Install them before running diagnostics so the key checks match the assembled control feel.
5. Connect audio output to headphones, speakers, or a mixer.
6. Connect power to the USB-C breakout.

Do not power the device from the Raspberry Pi power connector.

If you connect the Pi USB data/gadget port to a computer, remember that a normal USB cable carries 5V too. Octessera can configure the gadget, but it cannot make the Pi politely decline that power. Use a data-only cable or a power-isolating adapter if the instrument is already powered through the enclosure USB-C port.

Before applying power, check the NeoKey and NeoTrellis connector orientation again. `INT` should be on the south side.

Wait for the Pi to boot. First boot can take a while, but you should soon see the splashscreen.

Once it is up, check that none of the elements report an error. The OLED, NeoKey, and NeoTrellis can flash magenta in case of an electrical issue. The top NeoKey should light up magenta; that is intended because it is the Back button.

Then turn the main encoder to select the System menu, and click the main encoder to enter it. In the System menu, scroll to and run the hardware diagnostics before assembling the enclosure. Complete the guided checks for display, grid, keys, encoders, and audio while the boards are still accessible. The diagnostics can also detect inconsistent button or encoder signals. A couple of warnings are usually okay, but if the diagnostics report actual errors, double-check your soldering and components.

If the hardware does not come up, stop and use the manual hardware checks in [`../../hardware/docs/manual-hardware-test-suite.md`](../../hardware/docs/manual-hardware-test-suite.md).

## Enclosure assembly

Only assemble the enclosure after the electrical test and System-menu diagnostics pass.

Before you start with the enclosure, you need to remove the keyswitches from the NeoKey, but you can leave the keycaps on.
Remove the Raspberry Pi microSD card and OLED microSD card first. They can catch on the enclosure and break during installation.

1. Place the bottom enclosure on the bench.
   - Before closing the case, it can also be a useful soldering fixture: set the NeoTrellis array upside-down in the bottom, secure it with its top pins so the four boards stay perfectly aligned, then solder the boards to one another.
2. Put the PCB and NeoTrellis array onto the taller pillars.
3. Add the 18 separate standoff pillars between the bottom supports and the plug-in modules:
   - Use 8 of the 9.5mm standoff pillars for the OLED and audio/DAC board.
   - Use the 10 pieces of 10mm standoff pillars for the Raspberry Pi, power breakout, and NeoKey.
   - Printing the 9.5mm, and 10mm support parts in different colors makes them easier to tell apart during assembly.
   - For each plug-in module, remove the module, add the standoff, then reinstall the module. The standoffs' pins might take a little force to go through the component's mount holes and into the pillars, but if you are firm but gentle it will work.
   - You do not need separate standoff pillars for the NeoTrellis array. Its eight pins go straight into the integrated bottom pillars.
4. Press in all 26 top pins:
   - 18 pins go into the separate standoff pillars.
   - 8 pins go into the NeoTrellis array's integrated bottom pillars. It might be a bit tight due to the female connectors on the bottom, since the pillars are flared a bit for stability, but it will end up fitting nicely.
   - During final assembly, a small drop of glue on the top-pin can keep pins from falling out if the device is turned upside down.
   - The dowel/top-pin system can hold the enclosure together on its own. If a pin does not secure enough, use pliers to gently squeeze the ball at the end of the pin for a tighter fit. Gently is the magic word here; the tiny mushroom is brave, not immortal.
5. Place one silicone 4x4 keypad on each NeoTrellis board. Make sure the pads sit flat and line up with the 8x8 opening before closing the case.
6. Optional but recommended: install all 8 M3 heat-set inserts into the underside of the enclosure top with a soldering iron or insert tool.
7. Place the enclosure top over the assembly. It is easiest to slip the top on from the left/west side first so the ports pass through their holes, then lower the right/east side. The guide walls and standoff pins should locate the parts without forcing them.
8. Install the four printed encoder knobs from `release-artifacts/enclosure/stl/` or the matching multicolor 3MF files. Check the fit before pressing them fully down: they should slide on with a decent amount of friction, but not so tightly that removal would require force. If the fit is too tight, scale the encoder cap models up slightly in the X/Y plane before printing another set.
9. Turn the device over carefully.
10. Optional but recommended: install all 8 bottom screws into the recessed holes and tighten them into the heat-set inserts. If the printed pins already hold everything securely and the device will live a gentle bench life, you can leave the screws out.
11. Add rubber feet or screw-hole covers if desired.

Tighten screws gently. If the top does not sit flat, stop and find the interference instead of forcing the case closed.

## Final checks

1. Connect power through the USB-C breakout.
2. Wait for boot.
3. Confirm input from all encoders, NeoKey switches, and NeoTrellis buttons.
4. Confirm the OLED is readable.
5. Confirm audio output from the DAC.
6. Confirm the Pi microSD, OLED microSD, audio, USB-C power, Pi mini-HDMI, and Pi USB data openings are accessible.

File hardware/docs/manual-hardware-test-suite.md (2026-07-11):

# Manual Hardware Test Suite

Use this checklist for hands-on hardware bring-up when no OLED is installed. The operator watches the hardware while the test runner controls the Pi over SSH.

## Starting State

- Pi is reachable as `pi@192.168.0.211`.
- `octessera.service` is disabled and inactive unless a test step explicitly starts it.
- OLED is removed.
- NeoTrellis, NeoKey, DAC/audio, encoders, and power are connected.

Before each session:

```powershell
./tools/pi/pi-preflight.ps1 -Target pi@192.168.0.211
```

After flashing a fresh image, verify the app can reboot and shut down without broad passwordless sudo:

```bash
sudo test -f /etc/sudoers.d/octessera-shutdown
sudo visudo -cf /etc/sudoers.d/octessera-shutdown
sudo -n /usr/bin/systemctl reboot --dry-run
sudo -n /usr/bin/systemctl poweroff --dry-run
```

Expected:

- `/etc/sudoers.d/octessera-shutdown` exists and parses cleanly.
- The dry-run reboot and poweroff commands do not prompt for a password.
- No broad `NOPASSWD: ALL` rule is required for octessera power controls.

Then confirm the app is stopped:

```bash
sudo systemctl disable octessera.service
sudo systemctl stop octessera.service
```

## 1. Bus And Power Baseline

Run with the app stopped:

```bash
pinctrl get 2
pinctrl get 3
sudo i2cdetect -y -r 1 0x2e 0x3f
vcgencmd get_throttled
aplay -l
```

Expected:

- `GPIO2` / SDA and `GPIO3` / SCL are high when idle.
- NeoTrellis appears at `0x2E`, `0x2F`, `0x30`, `0x31`.
- NeoKey appears at `0x3F`.
- `throttled=0x0`.
- ALSA lists `snd_rpi_hifiberry_dac` / `pcm5102a`.

Stop if the clean scan does not match. Fix wiring before running active tests.

## 2. NeoTrellis LED Sweep

Goal: prove all 64 grid LEDs can be addressed and confirm physical coordinate orientation.

Test behavior to run from code for up to 90 seconds, or until the operator presses Enter:

1. Clear all grid LEDs.
2. Light each physical 4x4 board address as a different solid color:
   - `0x2E`: magenta
   - `0x2F`: green
   - `0x30`: cyan
   - `0x31`: white
3. Sweep one yellow pixel left-to-right, bottom-to-top in runtime grid coordinates.
4. Light the four logical corners:
   - `(0,0)` magenta
   - `(7,0)` green
   - `(0,7)` cyan
   - `(7,7)` white

Operator records:

- Whether all LEDs light.
- Whether colors match.
- Whether `(0,0)` appears at the lower-left of the play surface. If it appears at the upper-left, the HAL Y mapping is inverted.
- Any rotated, mirrored, or board-swapped regions.

## 3. NeoTrellis Button Events

Goal: prove all 64 grid buttons generate press and release events.

Test behavior to run from code for up to 90 seconds, or until the operator presses Enter:

1. Clear grid LEDs.
2. On every grid press, log `grid_press x y` and light that cell yellow.
3. On release, log `grid_release x y` and dim that cell cyan.
4. Keep a count of seen cells.
5. Print missing coordinates after each pass.

Manual pass:

- Press each cell once, left-to-right, bottom-to-top.
- Repeat the four corners.
- Hold two adjacent cells briefly to check multi-key handling.

Expected:

- Every press and release logs exactly once.
- Coordinates match lower-left runtime semantics.
- No stuck cells remain lit as pressed after release.

## 4. NeoKey LED And Button Test

Goal: prove four keys and four LEDs work without OLED feedback.

Test behavior to run from code:

1. Light NeoKey LEDs one at a time:
   - key 0 magenta
   - key 1 green
   - key 2 cyan
   - key 3 white
2. Then set all keys dim gray.
3. Confirm hands-off readiness, then run a no-touch idle noise check across NeoTrellis, NeoKey, and encoders. Confirmed input during this phase is a failure. Raw NeoKey one-sample glitches whose immediate reread burst is clean are warnings within tolerance.
4. On press, log and set pressed key bright white.
5. On release, log and return it to dim gray.

Expected logical mapping:

| NeoKey index | Runtime input |
|---:|---|
| 0 | Back / `button_a` |
| 1 | Space / `button_s` |
| 2 | Shift / `button_shift` |
| 3 | Fn / `button_fn` |

Operator records:

- Physical left-to-right order.
- Any LED color-order mismatch.
- Any missed press/release.
- Any idle ghost press, encoder event, grid event, or raw noise warning on any input.
- NeoKey raw one-sample glitches whose immediate reread burst is clean are reported as warnings within tolerance, because runtime input confirmation rejects them.

## 5. Encoder Turn And Click Test

Goal: prove all encoder A/B pins and push switches work.

Test behavior to run from code:

1. Log every encoder turn as `encoder_turn id delta`.
2. Log every encoder click as `encoder_press id`.
3. Optionally flash NeoKey key 0 on main encoder input and NeoKey keys 1-3 for aux encoders.

Expected IDs:

| Physical control | Runtime ID |
|---|---|
| Main encoder | `main` |
| Aux 1 | `aux1` |
| Aux 2 | `aux2` |
| Aux 3 | `aux3` |

Manual pass per encoder:

1. Turn one detent clockwise.
2. Turn one detent counter-clockwise.
3. Turn quickly for several detents.
4. Press and release the push switch.

Record:

- Direction polarity.
- Bounce or duplicate clicks.
- Missing detents.
- Wrong encoder ID.

## 6. Audio Output Test

The test harness asks the operator to connect speakers or headphones and set a safe volume before playing the direct ALSA tone:

```bash
timeout 15 speaker-test -D hw:0,0 -c 2 -t sine -f 440 -l 1
```

Expected:

- Audible 440 Hz tone.
- No underrun or device-open error.

Then run a runtime audio smoke test:

1. Start the app only after I2C devices are healthy.
2. Trigger a simple internal synth note from code or a known grid action.
3. Confirm output through the DAC path, not HDMI or headphone fallback.

## 7. Integrated Runtime Smoke Test

Use after individual hardware tests pass.

1. Start `octessera.service` manually.
2. Watch logs:

   ```bash
   journalctl -u octessera.service -f
   ```

3. Confirm no `critical hardware init failed` messages.
4. Press grid cells and NeoKeys.
5. Turn and click encoders.
6. Confirm audio still works.
7. Stop the service and verify the I2C bus releases:

   ```bash
   sudo systemctl stop octessera.service
   pinctrl get 2
   pinctrl get 3
   sudo i2cdetect -y -r 1 0x2e 0x3f
   ```

Expected:

- Service stays active.
- No restart loop.
- I2C devices remain detectable after service stop.
- Runtime input/output behavior matches hardware semantics.

## Test Harness Command

Run the no-OLED interactive hardware-test mode directly over SSH:

```bash
sudo systemctl disable octessera.service
sudo systemctl stop octessera.service
/usr/local/bin/octessera-pi --hardware-test
```

The mode initializes NeoTrellis, NeoKey, DAC, and encoders without requiring an OLED. It then runs the LED checks, logs grid/key/encoder events to stdout, and launches the ALSA test tone.
It prints a final `SUMMARY` with warning and failure counts.

For unattended launch, set `OCTESSERA_PI_HARDWARE_TEST=1` instead of passing `--hardware-test`.

To run only the no-touch input noise check:

```bash
sudo systemctl disable octessera.service
sudo systemctl stop octessera.service
/usr/local/bin/octessera-pi --hardware-noise-test
```

For unattended no-touch-only launch, set `OCTESSERA_PI_HARDWARE_NOISE_TEST=1`.
The noise-only mode also prints a final `SUMMARY`. Warnings indicate raw noise that is below the runtime confirmation threshold; failures indicate confirmed input, read failures, or encoder/grid idle events.

Use skip flags to isolate one hardware family while another is disconnected or suspect:

```bash
/usr/local/bin/octessera-pi --hardware-noise-test --skip-trellis
/usr/local/bin/octessera-pi --hardware-noise-test --skip-neokey
/usr/local/bin/octessera-pi --hardware-noise-test --skip-encoders
```

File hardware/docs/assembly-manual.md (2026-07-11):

# octessera hardware assembly manual

This guide builds the standalone Octessera instrument: PCB, soldered controls, plug-in modules, NeoTrellis grid, Raspberry Pi image, and enclosure.

The hardware is still being fit-tested. Check the current enclosure files before ordering printed parts, and do the slow fit checks before you close the box. Tiny clearances are where instruments learn humility.

If you are new here, start with the friendlier map in [`../../userdocs/README.md`](../../userdocs/README.md), then come back with a soldering iron and snacks.

## Source files

- Gerbers for PCB fabrication: [`../../release-artifacts/pcb/gerber/gerber.zip`](../../release-artifacts/pcb/gerber/gerber.zip)
- Schematic: [`../pcb/octessera.kicad_sch`](../pcb/octessera.kicad_sch)
- PCB layout: [`../pcb/octessera.kicad_pcb`](../pcb/octessera.kicad_pcb)
- Wiring reference: [`pinout-and-connections.md`](pinout-and-connections.md)
- Pi setup and bring-up: [`pi-bring-up.md`](pi-bring-up.md)
- Enclosure reference: [`../enclosure/README.md`](../enclosure/README.md)
- User docs home: [`../../userdocs/README.md`](../../userdocs/README.md)

## BOM

### PCB and electronics

| Qty | Item | Exact/current part | Notes |
|---:|---|---|---|
| 1 | Custom PCB | Fabricate from [`../../release-artifacts/pcb/gerber/gerber.zip`](../../release-artifacts/pcb/gerber/gerber.zip) | Order as a two-layer PCB unless the Gerber notes say otherwise. |
| 4 | NeoTrellis 4x4 driver PCB | [Adafruit `3954`](https://www.adafruit.com/product/3954), Mouser `485-3954` | Forms the 8x8 grid. |
| 4 | Silicone 4x4 keypad | [Adafruit `1611`](https://www.adafruit.com/product/1611), Mouser `485-1611` | One per NeoTrellis board. |
| 1 | NeoKey 1x4 QT | [Adafruit `4980`](https://www.adafruit.com/product/4980), Mouser `485-4980` | Holds the four Cherry MX keys. |
| 1 | Raspberry Pi Zero 2 W with header | [Raspberry Pi Zero 2 W](https://www.raspberrypi.com/products/raspberry-pi-zero-2-w/), Mouser `358-SC0721`, Raspberry Pi `SC0721` | Use the headered version. |
| 1 | SSD1351 OLED breakout with microSD holder | [Adafruit `1431`](https://www.adafruit.com/product/1431), Mouser `485-1431` | SPI display. |
| 1 | PCM5102 I2S DAC | [Adafruit `6250`](https://www.adafruit.com/product/6250), Mouser `485-6250` | Line/headphone output path. |
| 1 | USB-C power breakout | [Adafruit `4090`](https://www.adafruit.com/product/4090), Mouser `485-4090` | Power the device here, not through the Pi. |
| 4 | Horizontal rotary encoder with switch | [RS `781-6811`](https://at.rs-online.com/web/p/mechanische-drehgeber/7816811), Bourns `PEC12R-4225F-S0024` | The PCB uses four encoders. |
| 1 | Polarized capacitor | [`470uF`, 16V, radial, about 8x12mm](https://de.aliexpress.com/item/1005010415990713.html) | PCB footprint: `CP_Radial_D8.0mm_P3.50mm`. Any equivalent 470uF polarized radial capacitor with 3.5mm lead pitch and >5V rating is fine. |
| 1 | 1x5 right-angle female socket/header, 2.54mm pitch | [2.54mm right-angle female header strip](https://de.aliexpress.com/item/32896617287.html) | Cut to 5 pins for the NeoTrellis connector on the PCB. |
| 1 | 5-wire female-to-male Dupont cable, about 5cm | [Female-to-male Dupont jumper cable set](https://de.aliexpress.com/item/1005003683781229.html) | Use five adjacent leads, about 5cm long, to connect the NeoTrellis array to the PCB. |
| several | Low-profile female header/socket strips, 2.54mm pitch | [Round-pin 2.54mm header/socket strip](https://de.aliexpress.com/item/1005006673257121.html) or [round-pin 2.54mm header/socket strip](https://de.aliexpress.com/item/4001122376295.html) | Cut to length for Pi, OLED, DAC, power breakout, and other plug-in modules. Confirm the socket height before ordering. |
| 4 | Cherry MX-compatible key switches | [Cherry MX Black switches](https://www.amazon.de/-/en/CHERRY-Mechanical-Keyboard-Switches-without/dp/B0CBS4HJJR?th=1), or any MX-compatible switch | Install into the NeoKey after bring-up. |
| 1 | MicroSD card for Raspberry Pi | 16GB or larger recommended | Flash the release image. |
| 1 | USB-C power supply | Regulated 5V supply, 3A minimum; 4A recommended for extra LED headroom | Connect only to the USB-C breakout. A 2A supply is likely marginal once the Pi and LEDs are running together. |
| 1 | Audio cable/headphones/speaker | 3.5mm audio | Used for test and operation. |

### 3D printed and mechanical parts

| Qty | Item | File/spec | Notes |
|---:|---|---|---|
| 1 | Enclosure top | `../../release-artifacts/enclosure/stl/case_top_two_level_cadquery.stl` | Generated from CadQuery. STEP file is also checked in. |
| 1 | Enclosure bottom | `../../release-artifacts/enclosure/stl/case_bottom_plate_cadquery.stl` | Current bottom plate with guide walls and screw holes. |
| 1 | Main encoder knob | Print `../../release-artifacts/enclosure/stl/encoder_cap_main_knurled_dots.stl` or use `../../release-artifacts/enclosure/3mf-multicolor/encoder_cap_main_knurled_dots_multicolor_flush.3mf` | Main encoder cap. Printed version uses the dot-ring marking. |
| 3 | Aux encoder knobs | Print `../../release-artifacts/enclosure/stl/encoder_cap_aux*_ribbed_dot*.stl` or use matching `../../release-artifacts/enclosure/3mf-multicolor/encoder_cap_aux*_multicolor_flush.3mf` | Aux 1/2/3 caps. Printed versions use one, two, and three dots. |
| 4 | MX keycaps | Print `../../release-artifacts/enclosure/stl/mx_keycap_*.stl`, use matching `../../release-artifacts/enclosure/3mf-multicolor/mx_keycap_*_multicolor_flush.3mf`, or use any MX-stem keycap | Four NeoKey caps: back, play, shift, and function/layer. Transparent filament for the cap body and dark filament for the symbols works well, either with a filament swap for the last layers or multi-material printing. |
| 8 | 9.5mm standoff pillar | Print `../../release-artifacts/enclosure/stl/standoff_pillar_9_5mm.stl` and matching `../../release-artifacts/enclosure/3mf-multicolor/standoff_pillar_9_5mm.3mf`, or use compatible purchased stackable PCB standoffs | Use for the OLED and audio/DAC board support locations. |
| 10 | 10mm standoff pillar | Print `../../release-artifacts/enclosure/stl/standoff_pillar_10mm.stl` and matching `../../release-artifacts/enclosure/3mf-multicolor/standoff_pillar_10mm.3mf`, or use compatible purchased stackable PCB standoffs | Use for the Raspberry Pi, power breakout, and NeoKey support locations. NeoTrellis array pins go straight into the bottom's integrated pillars, so they do not need separate standoff pillars. |
| 26 | Standoff top pin | Print `../../release-artifacts/enclosure/stl/standoff_top_pin_thin_base.stl` and matching `../../release-artifacts/enclosure/3mf-multicolor/standoff_top_pin_thin_base.3mf`, or use compatible purchased stackable PCB standoff pins | 4 Pi + 4 audio/DAC + 4 OLED/screen + 4 NeoKey + 2 power + 8 NeoTrellis array pins = 26 total. |
| 8 | Heat-set insert | [M3 heat-set insert](https://de.aliexpress.com/item/1005012199553197.html), about `4.0-4.2mm` outer diameter and `5-6mm` long | Insert from the underside of the top. The linked kit includes multiple sizes; use the M3 inserts that fit the `4.2mm` pilot holes. |
| 8 | Screws | M3 x 8mm socket-head cap screw, DIN 912 / ISO 4762 style | Installed from the bottom. Use a head diameter no larger than `6.4mm` so it fits the counterbores. |
| 8 | Rubber feet or screw-hole plugs | Small adhesive feet | Optional, covers bottom screw holes and prevents sliding. |

Standoff STL attribution and purchase/source reference: the standoff models are based on [Stackable PCB Standoff by theduckom](https://www.printables.com/model/163087-stackable-pcb-standoff), licensed under [Creative Commons Attribution 4.0 International](https://creativecommons.org/licenses/by/4.0/).

### Tools and consumables

- Soldering iron and solder.
- Flush cutters.
- Small screwdriver and a longish bit for bottom screws.
- Optional: Heat-set insert tool.
- Multimeter.
- Raspberry Pi Imager.
- Optional: continuity tester, tweezers, helping hands, and magnifier.

## Before soldering

1. Inspect the PCB for visible manufacturing defects.
2. Confirm the PCB matches the current Gerber zip.
3. Sort sockets, headers, and modules before soldering.
4. Keep every module oriented the same way it will sit in the enclosure.
5. Mark the correct side of every module before soldering headers.

Headers on the wrong side are difficult to fix. Check the silkscreen, enclosure orientation, and module footprint before soldering. Best double-check every header before soldering it: the correct side matters for the PCB sockets, Pi, OLED, DAC/audio breakout, power breakout, NeoKey, and NeoTrellis connector.

Reference photos:

- [Soldered PCB overview](images/assembly/soldered-pcb.jpg)
- [Raspberry Pi Zero 2 W header side](images/assembly/pi-zero-2w.jpg)
- [OLED header side](images/assembly/oled.jpg)
- [Audio breakout header side](images/assembly/audio-breakout.jpg)
- [Power breakout header side](images/assembly/power-breakout.jpg)

## Solder the main PCB

Solder low-profile sockets and headers first. They define module height and alignment.

1. Solder the low-profile sockets for the Raspberry Pi, OLED, DAC, USB-C power breakout, and any other socketed modules.
2. Solder the 1x5 right-angle female socket for the NeoTrellis connector.
3. Solder `C1`, the `470uF` polarized capacitor. Match polarity to the PCB markings.
4. Solder the four rotary encoders into `SW1` through `SW4`.

You can leave the capacitor legs a little longer than usual so the capacitor can bend sideways if you need to save vertical space. Keep polarity correct and make sure the legs cannot short against nearby pads or metal parts.

The horizontal socket for the NeoTrellis array can be a tight fit near the case pillar that supports the NeoTrellis. Consider bending the socket legs slightly before soldering, or use a vertical connector if your build has enough space. If you plug the cable in before mounting the NeoTrellis array on the pillars, it will be very tight, but will fit (barely).

Do not install plug-in modules yet.

## Build the NeoTrellis array

The four NeoTrellis boards form one 8x8 grid.

1. Arrange the boards as viewed from the play surface:
   - upper left
   - upper right
   - lower left
   - lower right
2. Solder the boards together with pin links between adjacent edges.
3. Add the external connector pins to the left side of the upper-left NeoTrellis board.
4. Set the NeoTrellis addresses:

   | Position | Jumpers | Address |
   |---|---|---:|
   | upper left | none | `0x2E` |
   | upper right | A0 | `0x2F` |
   | lower left | A1 | `0x30` |
   | lower right | A0 + A1 | `0x31` |

Use the reference photos to confirm the soldered address jumper pads:

- [NeoTrellis address jumper pads](images/assembly/neotrellis-address-jumpers.jpg)

5. Set the NeoKey address by soldering A0, A1, A2, and A3. Leave A4 open. The expected address is `0x3F`.

- [NeoKey address jumper pads](images/assembly/neokey-address-jumpers.jpg)

The NeoKey and NeoTrellis connector are the two parts that are easiest to plug in backwards. Double-check their orientation before powering the device. The simplest check is that `INT` should always be on the south side.

## Flash the Raspberry Pi image

1. Download the latest release image from the project releases. It is named like:

   ```text
   octessera-<version>-pi-zero-2w.img.zip
   ```

2. Flash it to the Pi microSD card with Raspberry Pi Imager.
3. Configure WiFi, SSH, hostname, and locale in Raspberry Pi Imager if you need network access.
4. Insert the microSD card into the Raspberry Pi.

You can flash the downloaded `.img.zip` directly with Raspberry Pi Imager by choosing **Use custom** and selecting the ZIP. You do not need to extract the ZIP first.

The release also includes Raspberry Pi Imager metadata in two places:

- inside the image ZIP as `os_list.rpi-imager-manifest`;
- next to the image ZIP as `octessera-<version>-pi-zero-2w.rpi-imager-manifest`.

If you want octessera to appear as a custom OS entry in Raspberry Pi Imager, use the standalone `.rpi-imager-manifest` release asset as Imager's custom repository manifest. Loading the manifest/custom image this way lets Raspberry Pi Imager configure locale, WiFi, SSH, hostname, and user settings before flashing.

In Raspberry Pi Imager, open **App Options**, press **Edit** next to **Content Repository**, then choose one of these options:

- **Use custom file**: select the downloaded `.rpi-imager-manifest` file.
- **Use custom URL**: paste the manifest URL from the GitHub release.

Then press **Apply and Restart**. After Imager restarts, the octessera image will show up in the **OS** list after you have selected your device type.

Reference screenshots:

- [Raspberry Pi Imager options](images/assembly/rpi-imager-options.png)
- [Content Repository setting](images/assembly/rpi-content-repository.png)
- [Custom repository source](images/assembly/rpi-repository-source.png)

You can also start Imager with the manifest URL from the command line, for example:

```powershell
rpi-imager --repo "https://github.com/nexxyz/octessera/releases/download/v<version>/octessera-<version>-pi-zero-2w.rpi-imager-manifest"
```

Use the actual release tag and version from the release page. The embedded manifest inside the ZIP is for packaged metadata; do not extract the ZIP just to load the manifest.

For manual Pi setup and diagnostics, see [`pi-bring-up.md`](pi-bring-up.md).

## First electrical assembly

1. Insert the Raspberry Pi, OLED, DAC, USB-C power breakout, and NeoKey into their sockets.
2. Connect the NeoTrellis array to the PCB with the short 5-wire female-to-male Dupont cable.
3. Install the Cherry MX switches into the NeoKey.
4. Add the four keycaps. Use either printed keycaps from `release-artifacts/enclosure/stl/` or purchased MX-stem keycaps. Install them before running diagnostics so the key checks match the assembled control feel.
5. Connect audio output to headphones, speakers, or a mixer.
6. Connect power to the USB-C breakout.

Do not power the device from the Raspberry Pi power connector.

Before applying power, check the NeoKey and NeoTrellis connector orientation again. `INT` should be on the south side.

Wait for the Pi to boot. First boot can take a while, but you should soon see the splashscreen.

Once it is up, check that none of the elements report an error. The OLED, NeoKey, and NeoTrellis can turn completely red in case of an electrical issue. The top NeoKey should light up red; that is intended because it is the Back button.

Then turn the main encoder to select the System menu, and click the main encoder to enter it. In the System menu, scroll to and run the hardware diagnostics before assembling the enclosure. Complete the guided checks for display, grid, keys, encoders, and audio while the boards are still accessible. The diagnostics can also detect inconsistent button or encoder signals. A couple of warnings are usually okay, but if the diagnostics report actual errors, double-check your soldering and components.

If the hardware does not come up, stop and use the bring-up checks in [`pi-bring-up.md`](pi-bring-up.md).

## Enclosure assembly

Only assemble the enclosure after the electrical test and System-menu diagnostics pass.

Before you start with the enclosure, you need to remove the keyswitches from the NeoKey, but you can leave the keycaps on.

1. Place the bottom enclosure on the bench.
2. Put the PCB and NeoTrellis array onto the bottom.
   - Remove the Raspberry Pi microSD card and OLED microSD card first. They can catch on the enclosure and break during installation.
3. Add the 18 separate standoff pillars between the bottom supports and the plug-in modules:
   - Use 9.5mm standoff pillars for the OLED and audio/DAC board.
   - Use 10mm standoff pillars for the Raspberry Pi, power breakout, and NeoKey.
   - Printing the 9mm, 9.5mm, and 10mm support parts in different colors makes them easier to tell apart during assembly.
   - For each plug-in module, remove the module, add the standoff, then reinstall the module.
   - You do not need separate standoff pillars for the NeoTrellis array. Its eight pins go straight into the integrated bottom pillars.
4. Press in all 26 top pins:
   - 18 pins go into the separate standoff pillars.
   - 8 pins go into the NeoTrellis array's integrated bottom pillars.
   - During final assembly, a small drop of glue on the top-pin can keep pins from falling out if the device is turned upside down.
5. Place one silicone 4x4 keypad on each NeoTrellis board. Make sure the pads sit flat and line up with the 8x8 opening before closing the case.
6. Insert the M3 heat-set inserts into the underside of the enclosure top with a soldering iron or insert tool.
7. Place the enclosure top over the assembly. It is easiest to slip the top on from the left/west side first so the ports pass through their holes, then lower the right/east side. The guide walls and standoff pins should locate the parts without forcing them.
8. Install the four printed encoder knobs from `release-artifacts/enclosure/stl/` or the matching multicolor 3MF files. Check the fit before pressing them fully down: they should slide on with a decent amount of friction, but not so tightly that removal would require force. If the fit is too tight, scale the encoder cap models up slightly in the X/Y plane before printing another set.
9. Turn the device over carefully.
10. Install the bottom screws into the recessed holes and tighten them into the heat inserts.
11. Add rubber feet or screw-hole covers if desired.

Tighten screws gently. If the top does not sit flat, stop and find the interference instead of forcing the case closed.

## Final checks

1. Connect power through the USB-C breakout.
2. Wait for boot.
3. Confirm input from all encoders, NeoKey switches, and NeoTrellis buttons.
4. Confirm the OLED is readable.
5. Confirm audio output from the DAC.
6. Confirm the Pi microSD, OLED microSD, audio, USB-C power, Pi mini-HDMI, and Pi USB data openings are accessible.

## Things to verify before ordering in quantity

- Confirm the selected M3 heat-set inserts fit the `4.2mm` pilot holes and that M3 x 8mm socket-head screws reach the inserts cleanly after printing.
- Final fit of the printed bottom, top, standoff pillars, top pins, keycaps, and encoder knobs.
- Whether the generic sockets you buy match the intended low profile.
- Whether the 5cm Dupont cable has enough slack after the NeoTrellis array is installed.
- Port alignment after printing with your printer and slicer.

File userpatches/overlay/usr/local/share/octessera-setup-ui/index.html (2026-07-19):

 

Octessera first boot setup

# Connect the instrument to Wi-Fi

This portal runs from the setup hotspot. It is meant for quick, careful setup next to the device.

Until setup finishes, anyone nearby who joins this Wi-Fi can configure the device. Stay close to it. SSH keys are recommended. If you use Armbian's own first-run login instead, change its default password right away.

## Welcome

The setup portal can hand this device a Wi-Fi network, SSH access, and a hostname in one pass.

- Choose the network the device should join.
- Pick SSH key or password access.
- Review everything before it leaves the hotspot.

Start setup

## Wi-Fi

Available networks Refresh scan

Or enter SSID manually

Wi-Fi password Country code

This network is open

Back Next

## SSH access

SSH keys are the safest option. Password access is available if you need it.

SSH key SSH password No SSH setup

Public key

Password Confirm password

Back Next

## Device name

Hostname (optional)

Leave it blank to keep the device default.

Back Review

## Review and connect

Back Stage and connect

## Setup sent

The device is leaving the setup hotspot and joining your Wi-Fi now.

If the captive portal disappears, that is the expected good news.

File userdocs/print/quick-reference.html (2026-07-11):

octessera

# quick reference

Controls, bindings, behaviors, and Sparks pages on one page.

## Regular controls

Turn Main | Menu navigation · navigate menu / edit value
Click Main | Menu selection · select, edit, confirm
Back | Exit location · exit edit, overlay, or menu level
Play | Transport · play or pause
Shift + Play | Stop · external sync arms resync
Shift + Back | Clear layer · re-initialize active layer
Shift + Fn + Main | Context help · hold modifiers, click row

## Navigation + bindings

Fn + left column | Navigate to Layer 1–8 · bottom row = layer 1
Hold Fn | Preview · cyan/green layers, yellow Sparks pages
Fn + right column | Navigate Sparks · exits if already active
Fn + Aux click | Bind focused value/action · value to turn, action to click

Auto-map maps Aux 1–3 to important values/actions in the current menu area. It temporarily overrides manual bindings.

1-Cutoff Aux 1 turn 1!Assign Aux 1 click

## Special grid modes

Sample assign | Shift + cell maps row; Shift + Fn + cell maps column
Probability map | Trigger chance: never, low, high, always
Sparks Mix | Grid becomes a mixer for each layer's volume
Sparks Pan | Grid moves around layers' stereo positions
Sparks FX | Press mapped cells to trigger live effects
Trigger Gate | Block, allow, or use custom probability per layer
Transpose | Temporarily transpose synth and MIDI layers
XY | Mappable two-axis surface for live-manipulating parameters

## Behaviors

none | Inactive layer | keys | Finger-drumming
sequencer | Manual rhythm anchor | looper | Recorded grid gestures
life | Birth/survival/death cells | brain | Pulses and trails
ant | Walking grid agent | bounce | Moving collisions
shapes | Geometric regions | raindrops | Drops and ripples
dla | Branching growth

## Triggers

activate | Cell turns on
stable | Cell stays on
deactivate | Cell turns off
scanned | Scanner finds active cell
scanned empty | Scanner visits inactive cell

## Patch orientation

1. Route sequencer or looper to sampler for a rhythm loop.
2. Add life, raindrops, bounce, or dla to a synth.
3. Use probability on sequencer cells so patterns feel alive.
4. Bind aux encoders to parameters or actions you keep reaching for.

Factory preset hint: life on Layer 1, sequencer rhythm on Layer 2.

If the grid behaves unexpectedly, check the OLED. You are probably in an overlay or Sparks page. Use Back or Fn to leave.

octessera · quick reference · controls, behaviors, Sparks

octessera

# cell state to sound

From behavior state and direct input to MIDI, internal audio, routing, and optional live FX.

Flowchart from behavior and cell state through trigger mapping, instrument routing, optional FX branches, MIDI, and audio output

octessera · cell state → behavior → triggers → Pulses → instrument → output

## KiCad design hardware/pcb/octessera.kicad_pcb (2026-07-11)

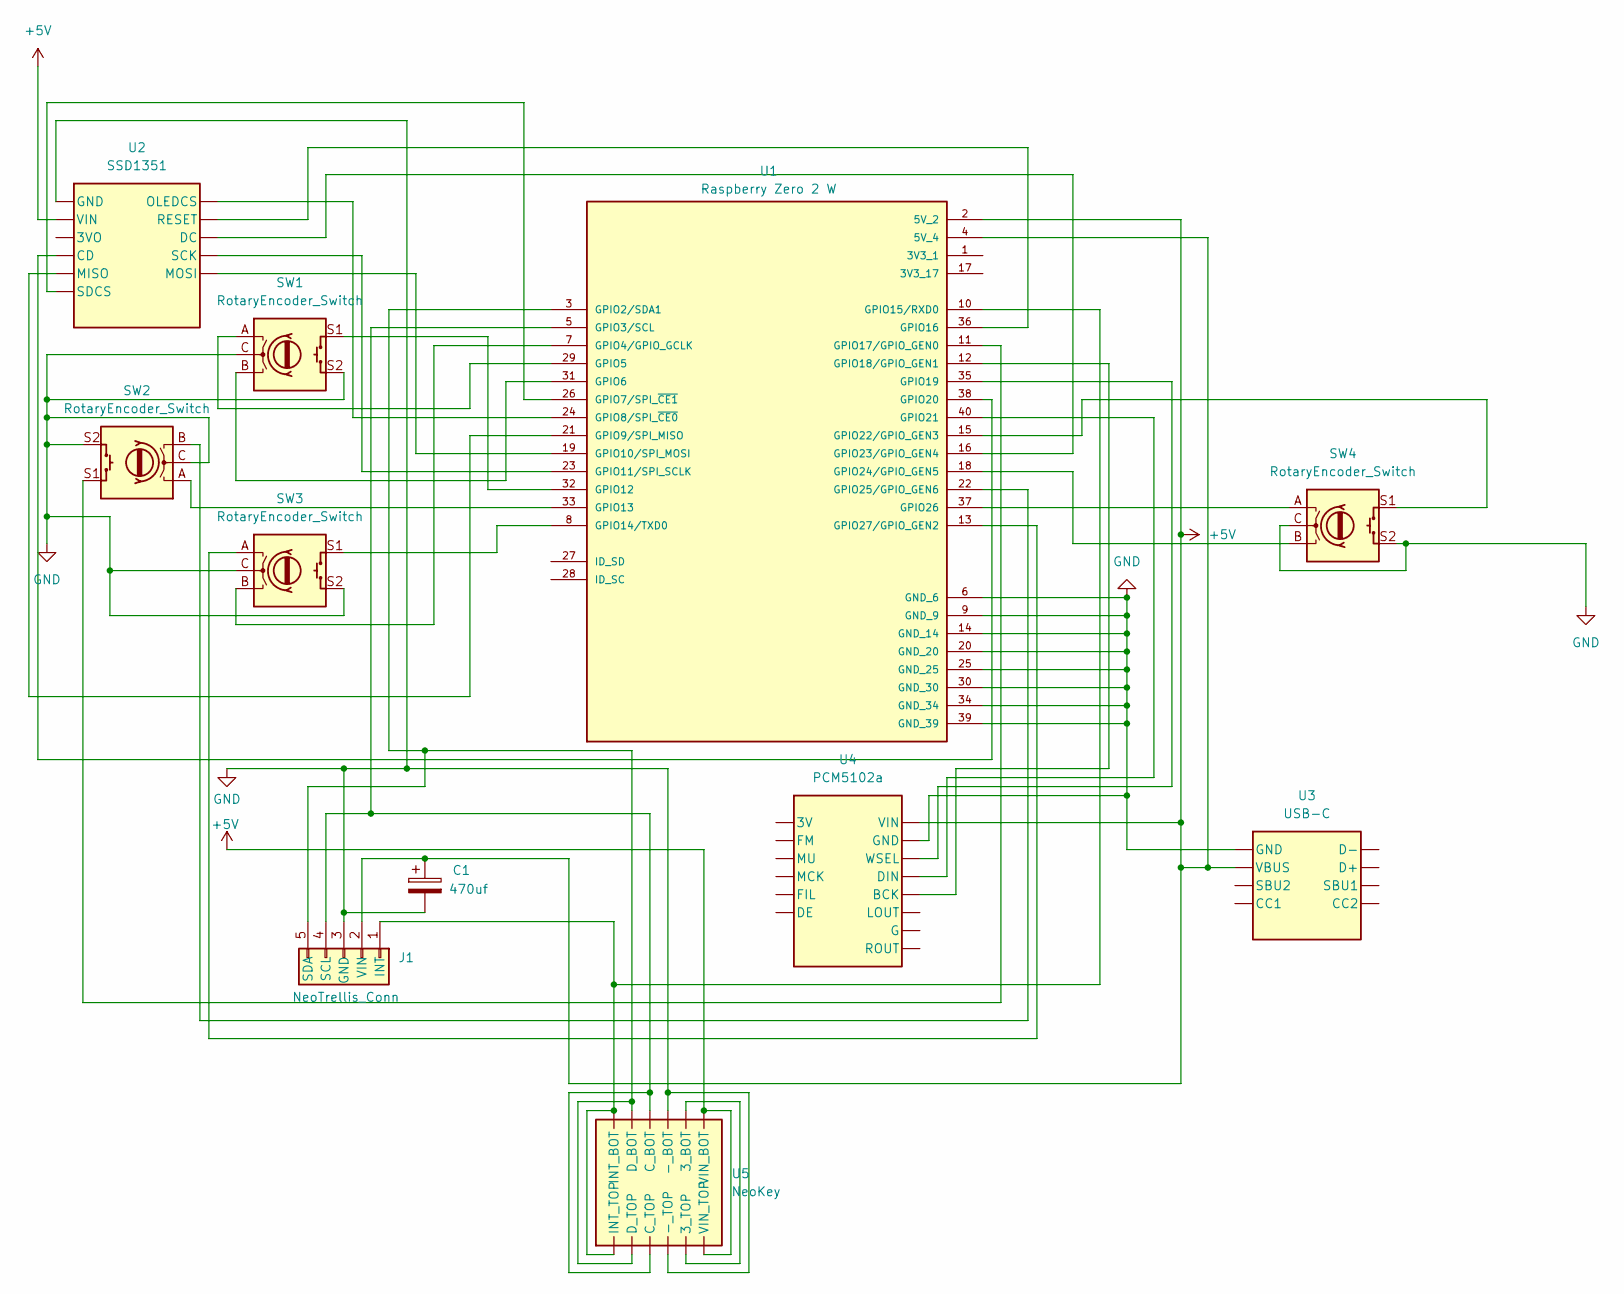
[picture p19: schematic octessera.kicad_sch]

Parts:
C1: 470uf; CP_Radial_D8.0mm_P3.50mm
J1: NeoTrellis_Conn; Adafruit_NeoTrellis_Connector_1x5
SW1, SW2, SW3, SW4: RotaryEncoder_Switch; RotaryEncoder_Alps_EC11E-Switch_Vertical_H20mm
U1: Raspberry Zero 2 W; MODULE_RASPBERRY_PI_ZERO_2_W; PARTREV April 2024
U2: SSD1351; Adafruit_SSD1351_OLED
U3: USB-C; Adafruit_USB_C_Breakout
U4: PCM5102a; Adafruit_PCM510x_I2S_DAC_6250
U5: NeoKey; Adafruit_NeoKey_1x4_QT

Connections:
+5V: C1.1, J1.2 (VIN), U1.2 (5V_2), U1.4 (5V_4), U2.+ (VIN), U3.VBUS, U4.VIN, U5.VIN (VIN_TOP)
GND: C1.2, J1.3 (GND), SW1.C, SW1.S2, SW2.C, SW2.S2, SW3.C, SW3.S2, SW4.C, SW4.S2, U1.6 (GND_6), U1.9 (GND_9), U1.14 (GND_14), U1.20 (GND_20), U1.25 (GND_25), U1.30 (GND_30), U1.34 (GND_34), U1.39 (GND_39), U2.G (GND), U3.GND, U4.GND, U5.- (-_TOP)
unnamed: J1.1 (INT), U1.10 (GPIO15/RXD0), U5.INT (INT_TOP)
unnamed: J1.4 (SCL), U1.5 (GPIO3/SCL), U5.C (C_TOP)
unnamed: J1.5 (SDA), U1.3 (GPIO2/SDA1), U5.D (D_TOP)
unnamed: SW3.B, U1.7 (GPIO4/GPIO_GCLK)
unnamed: SW1.A, U1.29 (GPIO5)
unnamed: SW1.B, U1.31 (GPIO6)
unnamed: U1.26 (GPIO7/SPI_~CE1), U2.SC (SDCS)
unnamed: U1.24 (GPIO8/SPI_~CE0), U2.OC (OLEDCS)
unnamed: U1.21 (GPIO9/SPI_MISO), U2.SO (MISO)
unnamed: U1.19 (GPIO10/SPI_MOSI), U2.SI (MOSI)
unnamed: U1.23 (GPIO11/SPI_SCLK), U2.CL (SCK)
unnamed: SW1.S1, U1.32 (GPIO12)
unnamed: SW2.A, U1.33 (GPIO13)
unnamed: SW3.S1, U1.8 (GPIO14/TXD0)
unnamed: U1.36 (GPIO16), U2.R (RESET)
unnamed: SW2.S1, U1.11 (GPIO17/GPIO_GEN0)
unnamed: U1.12 (GPIO18/GPIO_GEN1), U4.BCK
unnamed: U1.35 (GPIO19), U4.WSEL
unnamed: U1.38 (GPIO20), U2.CD
unnamed: U1.40 (GPIO21), U4.DIN
unnamed: SW4.S1, U1.15 (GPIO22/GPIO_GEN3)
unnamed: U1.16 (GPIO23/GPIO_GEN4), U2.DC
unnamed: SW4.B, U1.18 (GPIO24/GPIO_GEN5)
unnamed: SW2.B, U1.22 (GPIO25/GPIO_GEN6)
unnamed: SW4.A, U1.37 (GPIO26)
unnamed: SW3.A, U1.13 (GPIO27/GPIO_GEN2)

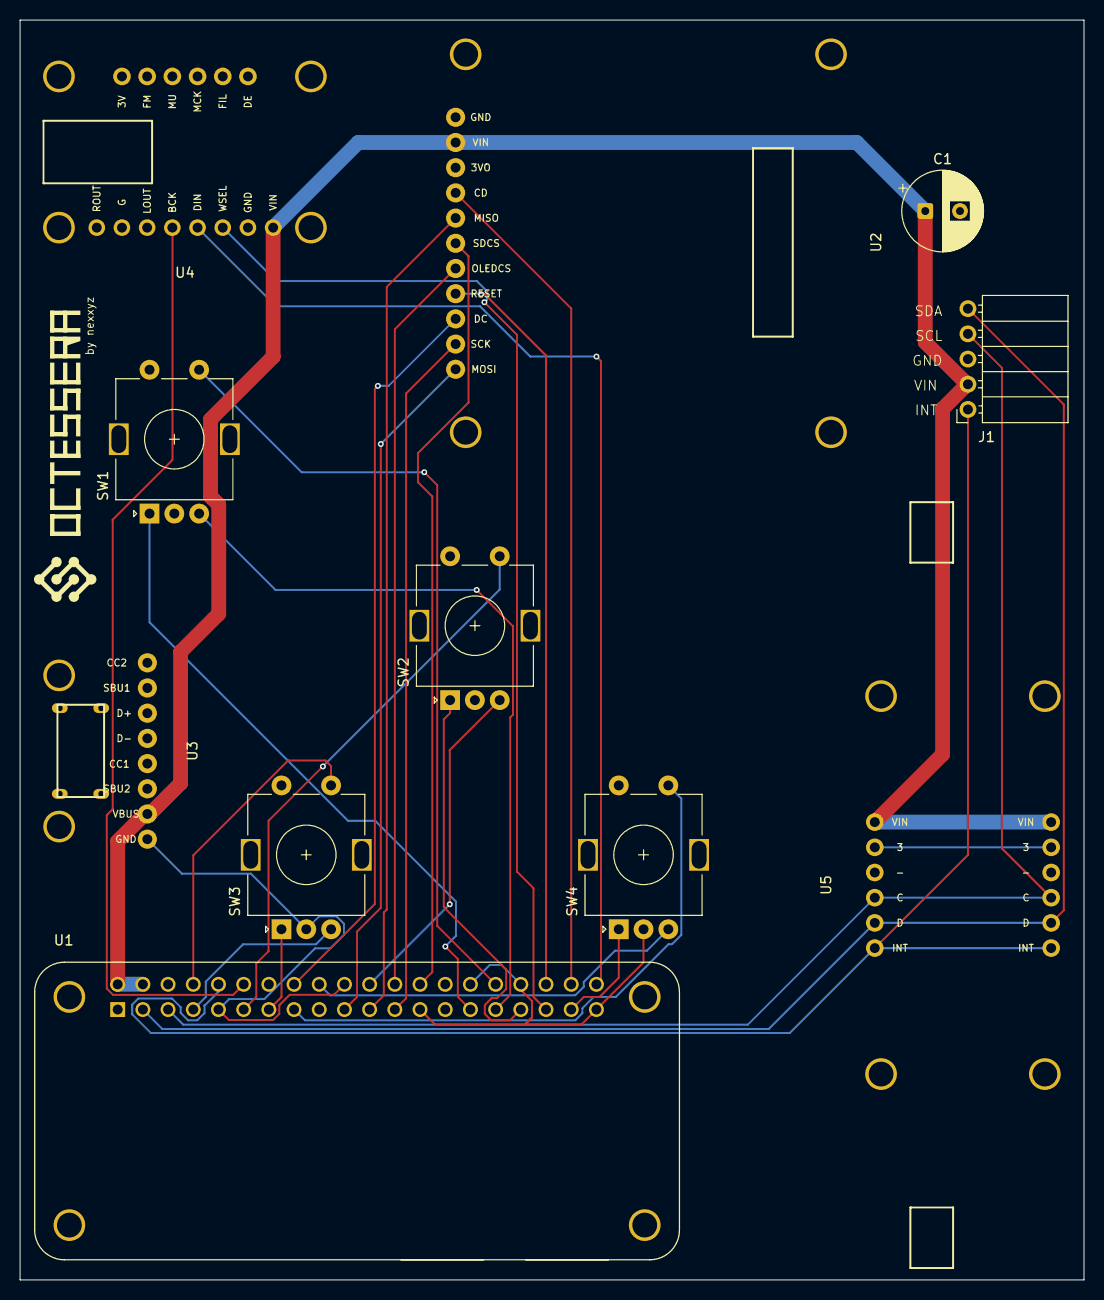
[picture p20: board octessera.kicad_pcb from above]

Board: 2 copper layers, 107.2 x 127.0 mm, 11 parts (0 on the bottom side), 28 nets.

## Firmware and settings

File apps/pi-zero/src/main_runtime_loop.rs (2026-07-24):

use crate::encoder_queue::PendingEncoderTurns;
use crate::host_adapter::{PiPlaybackHostAdapter, PiPowerRequest};
use crate::input::{encoder_press_message, MidiMessage};
use crate::render_loop::RenderWorker;
use crate::runtime_loop::{dispatch_runtime_message, handle_deferred_host_work};
use crate::ui_profile::UiProfiler;
use octessera_hal::encoder_gpio::HardwareEvent;
use playback_runtime::{
    HostMessage, NativeRunner, PlaybackRuntime, RuntimeTransportState, RuntimeUiPulse, SyncSource,
};
use std::sync::mpsc;
use std::time::{Duration, Instant};

const HARDWARE_EVENT_BUDGET: usize = 16;
const MIDI_REALTIME_BUDGET: usize = 32;
const IDLE_MAINTENANCE_INTERVAL: Duration = Duration::from_millis(50);

pub(crate) fn drain_midi_messages(
    midi_rx: &mpsc::Receiver<MidiMessage>,
    playback: &mut PlaybackRuntime,
    runner: &mut NativeRunner,
    adapter: &mut PiPlaybackHostAdapter,
) {
    for _ in 0..MIDI_REALTIME_BUDGET {
        let Ok(message) = midi_rx.try_recv() else {
            break;
        };
        match message {
            MidiMessage::Realtime { bytes } => {
                match playback.handle_midi_realtime_bytes_with_output(&bytes, runner, adapter) {
                    Ok(output) => {
                        for follow_up in output.follow_ups {
                            if let Err(error) =
                                dispatch_runtime_message(playback, runner, adapter, follow_up)
                            {
                                eprintln!("pi realtime MIDI follow-up failed: {error}");
                            }
                        }
                    }
                    Err(error) => eprintln!("pi realtime MIDI handling failed: {error}"),
                }
            }
        }
    }
}

pub(crate) fn drain_host_messages(
    input_rx: &mpsc::Receiver<HostMessage>,
    playback: &mut PlaybackRuntime,
    runner: &mut NativeRunner,
    adapter: &mut PiPlaybackHostAdapter,
) {
    for _ in 0..HARDWARE_EVENT_BUDGET {
        let Ok(message) = input_rx.try_recv() else {
            break;
        };
        dispatch_or_log(playback, runner, adapter, message);
    }
}

pub(crate) fn drain_encoder_events(
    event_rx: &mpsc::Receiver<HardwareEvent>,
    pending_encoder_turns: &mut PendingEncoderTurns,
    playback: &mut PlaybackRuntime,
    runner: &mut NativeRunner,
    adapter: &mut PiPlaybackHostAdapter,
) {
    for _ in 0..HARDWARE_EVENT_BUDGET {
        let Ok(event) = event_rx.try_recv() else {
            break;
        };
        let message = match event {
            HardwareEvent::EncoderTurn { id, delta } => {
                crate::wake_trace::log_encoder_event(event);
                pending_encoder_turns.enqueue(id, delta);
                continue;
            }
            HardwareEvent::EncoderPress { id } => {
                crate::wake_trace::log_encoder_event(event);
                flush_pending_encoder_turns(pending_encoder_turns, playback, runner, adapter);
                encoder_press_message(id)
            }
            HardwareEvent::EncoderRelease { .. } => {
                crate::wake_trace::log_encoder_event(event);
                continue;
            }
        };
        dispatch_or_log(playback, runner, adapter, message);
    }
}

#[allow(clippy::too_many_arguments)]
pub(crate) fn maybe_advance_runtime(
    last_tick: &mut Instant,
    tick_duration: Duration,
    last_snapshot_request: &mut Instant,
    snapshot_interval: Duration,
    last_render: &mut Instant,
    render_interval: Duration,
    last_rendered_snapshot_revision: &mut u64,
    transient_render_until: &mut Option<Instant>,
    _pending_encoder_turns: &mut PendingEncoderTurns,
    playback: &mut PlaybackRuntime,
    runner: &mut NativeRunner,
    adapter: &mut PiPlaybackHostAdapter,
    render_worker: &RenderWorker,
    ui_profiler: &mut UiProfiler,
) -> bool {
    let now = Instant::now();
    let effective_tick_duration = if runtime_tick_needed(playback) {
        tick_duration
    } else {
        IDLE_MAINTENANCE_INTERVAL
    };
    if now.duration_since(*last_tick) >= effective_tick_duration {
        advance_playback_if_due(
            now,
            last_tick,
            effective_tick_duration,
            last_snapshot_request,
            snapshot_interval,
            playback,
            runner,
            adapter,
            ui_profiler,
        );
    }
    request_periodic_snapshot_if_due(now, last_snapshot_request, playback, runner, adapter);
    service_render_if_due(
        now,
        last_render,
        render_interval,
        last_rendered_snapshot_revision,
        transient_render_until,
        playback,
        render_worker,
    );
    shutdown_if_requested(adapter, render_worker)
}

#[allow(clippy::too_many_arguments)]
fn advance_playback_if_due(
    now: Instant,
    last_tick: &mut Instant,
    tick_duration: Duration,
    last_snapshot_request: &mut Instant,
    snapshot_interval: Duration,
    playback: &mut PlaybackRuntime,
    runner: &mut NativeRunner,
    adapter: &mut PiPlaybackHostAdapter,
    ui_profiler: &mut UiProfiler,
) {
    let profile_enabled = ui_profiler.enabled();
    let lateness =
        profile_enabled.then(|| now.duration_since(*last_tick).saturating_sub(tick_duration));
    let elapsed = now.duration_since(*last_tick);
    *last_tick = now;
    if transport_snapshot_due(now, *last_snapshot_request, snapshot_interval, playback) {
        playback.request_next_snapshot();
        *last_snapshot_request = now;
    }
    let advance_started = profile_enabled.then(Instant::now);
    if let Err(error) = playback.advance_duration(elapsed, runner, adapter) {
        eprintln!("pi playback advance failed: {error}");
    }
    if let Err(error) = handle_deferred_host_work(playback, runner, adapter) {
        eprintln!("pi deferred host work failed: {error}");
    }
    if let (Some(lateness), Some(started)) = (lateness, advance_started) {
        ui_profiler.record_runtime(lateness, started.elapsed());
    }
}

fn transport_snapshot_due(
    now: Instant,
    last_snapshot_request: Instant,
    snapshot_interval: Duration,
    playback: &PlaybackRuntime,
) -> bool {
    is_internal_playing(playback) && now.duration_since(last_snapshot_request) >= snapshot_interval
}

fn request_periodic_snapshot_if_due(
    now: Instant,
    last_snapshot_request: &mut Instant,
    playback: &mut PlaybackRuntime,
    runner: &mut NativeRunner,
    adapter: &mut PiPlaybackHostAdapter,
) {
    if is_internal_playing(playback) {
        return;
    }
    if !timed_display_snapshot_due(now, *last_snapshot_request, runner) {
        return;
    }
    *last_snapshot_request = now;
    let message = periodic_snapshot_message(playback);
    dispatch_or_log(playback, runner, adapter, message);
}

fn timed_display_snapshot_due(
    now: Instant,
    last_snapshot_request: Instant,
    runner: &NativeRunner,
) -> bool {
    runner
        .next_timed_display_snapshot_deadline_after(Some(last_snapshot_request))
        .is_some_and(|deadline| now >= deadline)
}

fn periodic_snapshot_message(playback: &PlaybackRuntime) -> HostMessage {
    HostMessage::TransportPulseStep {
        pulses: 0,
        source: playback.config().sync_source.clone(),
        at_ppqn_pulse: playback
            .last_status()
            .map(|status| status.current_ppqn_pulse),
        request_snapshot: Some(true),
    }
}

pub(crate) fn flush_pending_encoder_turns(
    pending: &mut PendingEncoderTurns,
    playback: &mut PlaybackRuntime,
    runner: &mut NativeRunner,
    adapter: &mut PiPlaybackHostAdapter,
) {
    for message in pending.take_messages() {
        dispatch_or_log(playback, runner, adapter, message);
    }
}

fn dispatch_or_log(
    playback: &mut PlaybackRuntime,
    runner: &mut NativeRunner,
    adapter: &mut PiPlaybackHostAdapter,
    message: HostMessage,
) {
    let message = prepare_dispatch_message(playback, message);
    if let Err(error) = dispatch_runtime_message(playback, runner, adapter, message) {
        eprintln!("pi runtime dispatch failed: {error}");
    }
}

fn prepare_dispatch_message(playback: &PlaybackRuntime, message: HostMessage) -> HostMessage {
    match message {
        HostMessage::DeviceInput {
            input,
            request_snapshot: None,
        } if is_internal_playing(playback) => HostMessage::DeviceInput {
            input,
            request_snapshot: Some(false),
        },
        other => other,
    }
}

fn is_internal_playing(playback: &PlaybackRuntime) -> bool {
    playback.config().sync_source == SyncSource::Internal
        && playback
            .last_status()
            .is_some_and(|status| status.transport == RuntimeTransportState::Playing)
}

fn runtime_tick_needed(playback: &PlaybackRuntime) -> bool {
    playback.has_scheduled_midi() || is_internal_playing(playback)
}

#[allow(clippy::too_many_arguments)]
fn service_render_if_due(
    now: Instant,
    last_render: &mut Instant,
    render_interval: Duration,
    last_rendered_snapshot_revision: &mut u64,
    transient_render_until: &mut Option<Instant>,
    playback: &mut PlaybackRuntime,
    render_worker: &RenderWorker,
) {
    if now.duration_since(*last_render) < render_interval {
        return;
    }
    *last_render = now;
    let snapshot_revision = playback.last_snapshot_revision();
    if snapshot_revision == 0 {
        return;
    }
    let pulses = playback.drain_ui_pulses();
    update_transient_render_deadline(now, transient_render_until, &pulses);
    let snapshot_changed = *last_rendered_snapshot_revision != snapshot_revision;
    if !snapshot_changed
        && pulses.is_empty()
        && !transient_render_active(now, transient_render_until)
    {
        return;
    }
    let Some(snapshot) = crate::runtime_loop::latest_snapshot(playback).cloned() else {
        return;
    };
    if !render_worker.publish_snapshot(snapshot, pulses) {
        eprintln!("pi render worker rejected snapshot publication");
        return;
    }
    *last_rendered_snapshot_revision = snapshot_revision;
}

fn update_transient_render_deadline(
    now: Instant,
    transient_render_until: &mut Option<Instant>,
    pulses: &[RuntimeUiPulse],
) {
    for pulse in pulses {
        let duration_ms = match pulse {
            RuntimeUiPulse::TriggerPulse { duration_ms } => *duration_ms,
            RuntimeUiPulse::TransportFlash { duration_ms, .. } => *duration_ms,
        };
        let deadline = now + Duration::from_millis(duration_ms);
        *transient_render_until =
            Some(transient_render_until.map_or(deadline, |until| until.max(deadline)));
    }
}

fn transient_render_active(now: Instant, transient_render_until: &mut Option<Instant>) -> bool {
    let Some(deadline) = *transient_render_until else {
        return false;
    };
    if now < deadline {
        return true;
    }
    *transient_render_until = None;
    true
}

fn shutdown_if_requested(
    adapter: &mut PiPlaybackHostAdapter,
    render_worker: &RenderWorker,
) -> bool {
    let Some(request) = adapter.take_power_request() else {
        return false;
    };
    if !render_worker.publish_shutdown() {
        eprintln!("pi shutdown render acknowledgement timed out");
    }
    if let Err(error) = power_pi_system(request) {
        eprintln!("pi power request failed: {error}");
        return false;
    }
    true
}

fn power_pi_system(_request: PiPowerRequest) -> Result<(), String> {
    #[cfg(feature = "hardware-rpi-zero-2w")]
    {
        let attempts = power_command_attempts(_request);
        let mut errors = Vec::new();
        for (command, args) in attempts {
            match std::process::Command::new(command).args(*args).status() {
                Ok(status) if status.success() => return Ok(()),
                Ok(status) => errors.push(format!("{command} {args:?} exited with {status}")),
                Err(error) => errors.push(format!("{command} {args:?} failed to launch: {error}")),
            }
        }
        Err(errors.join("; "))
    }
    #[cfg(not(feature = "hardware-rpi-zero-2w"))]
    {
        Ok(())
    }
}

#[cfg(feature = "hardware-rpi-zero-2w")]
fn power_command_attempts(
    request: PiPowerRequest,
) -> &'static [(&'static str, &'static [&'static str])] {
    match request {
        PiPowerRequest::Reboot => &[
            ("sudo", &["-n", "/usr/bin/systemctl", "reboot"]),
            ("sudo", &["-n", "/bin/systemctl", "reboot"]),
            ("sudo", &["-n", "/usr/sbin/reboot"]),
            ("sudo", &["-n", "/sbin/reboot"]),
            ("/usr/bin/systemctl", &["reboot"]),
            ("/bin/systemctl", &["reboot"]),
            ("/usr/sbin/reboot", &[]),
            ("/sbin/reboot", &[]),
        ],
        PiPowerRequest::Shutdown => &[
            ("sudo", &["-n", "/usr/bin/systemctl", "poweroff"]),
            ("sudo", &["-n", "/bin/systemctl", "poweroff"]),
            ("sudo", &["-n", "/usr/sbin/poweroff"]),
            ("sudo", &["-n", "/sbin/poweroff"]),
            ("/usr/bin/systemctl", &["poweroff"]),
            ("/bin/systemctl", &["poweroff"]),
            ("/usr/sbin/poweroff", &[]),
            ("/sbin/poweroff", &[]),
        ],
    }
}

#[cfg(test)]
mod periodic_snapshot_tests {
    use super::*;
    use playback_runtime::RuntimeConfig;

    #[test]
    fn periodic_snapshot_message_requests_snapshot_without_advancing_pulses() {
        let playback = PlaybackRuntime::new(RuntimeConfig {
            sync_source: SyncSource::External,
            ..RuntimeConfig::default()
        });

        let HostMessage::TransportPulseStep {
            pulses,
            source,
            request_snapshot,
            ..
        } = periodic_snapshot_message(&playback)
        else {
            panic!("expected transport snapshot request");
        };

        assert_eq!(pulses, 0);
        assert_eq!(source, SyncSource::External);
        assert_eq!(request_snapshot, Some(true));
    }

    #[test]
    fn stopped_idle_maintenance_does_not_claim_snapshot_deadlines() {
        let playback = PlaybackRuntime::new(RuntimeConfig::default());
        let now = Instant::now();
        let stale_snapshot = now - Duration::from_secs(5);

        assert!(!transport_snapshot_due(
            now,
            stale_snapshot,
            Duration::from_millis(16),
            &playback
        ));
    }
}

#[cfg(all(test, feature = "hardware-rpi-zero-2w"))]
mod tests {
    use super::*;

    #[test]
    fn power_command_attempts_match_shutdown_sudoers_shape() {
        let shutdown = power_command_attempts(PiPowerRequest::Shutdown);
        assert!(shutdown
            .iter()
            .any(|attempt| *attempt == ("/usr/bin/systemctl", &["poweroff"])));
        assert!(shutdown
            .iter()
            .any(|attempt| *attempt == ("sudo", &["-n", "/usr/bin/systemctl", "poweroff"])));
        assert!(!shutdown
            .iter()
            .any(|(_, args)| args.contains(&"--no-block")));

        let reboot = power_command_attempts(PiPowerRequest::Reboot);
        assert!(reboot
            .iter()
            .any(|attempt| *attempt == ("/usr/bin/systemctl", &["reboot"])));
        assert!(reboot
            .iter()
            .any(|attempt| *attempt == ("sudo", &["-n", "/usr/bin/systemctl", "reboot"])));
        assert!(!reboot.iter().any(|(_, args)| args.contains(&"--no-block")));
    }
}

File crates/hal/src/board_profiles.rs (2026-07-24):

#[derive(Clone, Copy, Debug, Eq, PartialEq)]
pub struct EncoderPins {
    pub a: u8,
    pub b: u8,
    pub sw: u8,
}

pub const RASPBERRY_PI_ZERO_2W_ID: &str = "raspberry-pi-zero-2w";
pub const ORANGE_PI_ZERO_2W_ID: &str = "orange-pi-zero-2w";

pub struct BoardProfile {
    pub id: &'static str,
    pub i2c_bus: u8,
    pub i2c_path: &'static str,
    pub spi_bus: &'static str,
    pub oled_cs: u8,
    pub oled_dc: u8,
    pub oled_rst: u8,
    pub oled_sd_cs: u8,
    pub oled_sd_cd: u8,
    pub i2s_bck: u8,
    pub i2s_lrck: u8,
    pub i2s_din: u8,
    pub encoders: [EncoderPins; 1 + platform_core::AUX_ENCODER_COUNT],
    pub neokey_addr: u16,
    pub seesaw_int: u8,
    pub trellis_addrs: [u16; 4],
}

pub const RASPBERRY_PI_ZERO_2W: BoardProfile = BoardProfile {
    id: RASPBERRY_PI_ZERO_2W_ID,
    i2c_bus: 1,
    i2c_path: "/dev/i2c-1",
    spi_bus: "/dev/spidev0.0",
    oled_cs: 8,
    oled_dc: 23,
    oled_rst: 16,
    oled_sd_cs: 7,
    oled_sd_cd: 20,
    i2s_bck: 18,
    i2s_lrck: 19,
    i2s_din: 21,
    encoders: [
        EncoderPins { a: 6, b: 5, sw: 12 },
        EncoderPins {
            a: 25,
            b: 13,
            sw: 17,
        },
        EncoderPins {
            a: 4,
            b: 27,
            sw: 14,
        },
        EncoderPins {
            a: 24,
            b: 26,
            sw: 22,
        },
    ],
    neokey_addr: 0x3F,
    seesaw_int: 15,
    trellis_addrs: [0x2E, 0x2F, 0x30, 0x31],
};

pub const RPI_ZERO_2W: BoardProfile = RASPBERRY_PI_ZERO_2W;

#[cfg(test)]
mod tests {
    use super::{ORANGE_PI_ZERO_2W_ID, RASPBERRY_PI_ZERO_2W, RASPBERRY_PI_ZERO_2W_ID, RPI_ZERO_2W};
    use crate::pinmap;

    #[test]
    fn rpi_profile_matches_legacy_pinmap_constants() {
        assert_eq!(pinmap::I2C_BUS, RPI_ZERO_2W.i2c_bus);
        assert_eq!(pinmap::I2C_PATH, RPI_ZERO_2W.i2c_path);
        assert_eq!(pinmap::SPI_BUS, RPI_ZERO_2W.spi_bus);
        assert_eq!(pinmap::OLED_CS, RPI_ZERO_2W.oled_cs);
        assert_eq!(pinmap::OLED_DC, RPI_ZERO_2W.oled_dc);
        assert_eq!(pinmap::OLED_RST, RPI_ZERO_2W.oled_rst);
        assert_eq!(pinmap::OLED_SD_CS, RPI_ZERO_2W.oled_sd_cs);
        assert_eq!(pinmap::OLED_SD_CD, RPI_ZERO_2W.oled_sd_cd);
        assert_eq!(pinmap::I2S_BCK, RPI_ZERO_2W.i2s_bck);
        assert_eq!(pinmap::I2S_LRCK, RPI_ZERO_2W.i2s_lrck);
        assert_eq!(pinmap::I2S_DIN, RPI_ZERO_2W.i2s_din);
        assert_eq!(pinmap::ENCODERS, RPI_ZERO_2W.encoders);
        assert_eq!(pinmap::NEOKEY_ADDR, RPI_ZERO_2W.neokey_addr);
        assert_eq!(pinmap::SEESAW_INT, RPI_ZERO_2W.seesaw_int);
        assert_eq!(pinmap::TRELLIS_ADDRS, RPI_ZERO_2W.trellis_addrs);
    }

    #[test]
    fn profile_ids_are_distinct_and_rpi_alias_is_stable() {
        assert_eq!(RASPBERRY_PI_ZERO_2W.id, RASPBERRY_PI_ZERO_2W_ID);
        assert_ne!(RASPBERRY_PI_ZERO_2W_ID, ORANGE_PI_ZERO_2W_ID);
        assert_eq!(RPI_ZERO_2W.id, RASPBERRY_PI_ZERO_2W_ID);
        assert_eq!(RPI_ZERO_2W.encoders, RASPBERRY_PI_ZERO_2W.encoders);
    }
}

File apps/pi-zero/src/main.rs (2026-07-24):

mod audio;
mod audio_config_parse;
mod audio_hotplug;
mod audio_priority;
mod audio_stream_health;
mod board_profile;
mod candidate_readiness;
mod device_update;
mod diagnostics;
mod dsp_profile;
mod encoder_queue;
mod hardware_fault;
mod hardware_init;
mod hardware_test;
mod hardware_test_noise;
mod host_adapter;
mod host_audio_command;
mod host_audio_prep;
mod input;
mod main_paths;
mod main_runtime_loop;
mod oled_test;
mod persistence;
mod platform_service;
mod recording;
mod render;
mod render_loop;
mod runtime_loop;
mod runtime_thread;
mod sample_browser;
mod seesaw_io;
mod timing_probe;
mod ui_profile;
#[cfg(test)]
mod update_menu_fixture_tests;
mod usb_config;
mod wake_trace;

use audio::AudioManager;
use hardware_init::{init_encoders, init_hardware, HardwareDevices};
use input::{midi_realtime_message, MidiMessage};
use render::HardwareRenderTargets;
use render_loop::RenderWorker;
use std::sync::mpsc;
use std::sync::Arc;

use main_paths::{default_samples_dir, default_store_dir, ensure_runtime_dirs};

fn main() {
    if board_profile::metadata_requested() {
        board_profile::print_build_metadata();
        return;
    }

    let _ = simple_logger::init();

    run_requested_utility();

    if let Err(error) = board_profile::validate_runtime_profile() {
        eprintln!("{error}");
        std::process::exit(2);
    }

    println!("octessera - Pi native runtime");

    let hardware = match init_hardware() {
        Ok(devices) => devices,
        Err(fault) => hardware_fault::run_hardware_fault_mode(fault),
    };
    let (event_rx, _encoders) = match init_encoders() {
        Ok(encoders) => encoders,
        Err(mut fault) => {
            fault.attach_outputs(
                Some(hardware.oled),
                Some(hardware.trellis),
                Some(hardware.neokey),
            );
            hardware_fault::run_hardware_fault_mode(fault);
        }
    };
    let HardwareDevices {
        _i2c_bus,
        oled,
        trellis,
        neokey,
        input_interrupt,
        _dac,
    } = hardware;
    let seesaw_io = seesaw_io::spawn(trellis, neokey, input_interrupt);
    let store_dir = default_store_dir();
    let usb_config = usb_config::read_usb_runtime_config(&store_dir);
    let audio = init_audio(
        audio_output_buffer_frames_from_default_config(&store_dir),
        usb_config.audio_out,
    );

    let (midi_tx, midi_rx) = mpsc::channel::<MidiMessage>();
    let midi_handler = Arc::new(move |bytes: Vec<u8>| {
        if let Some(message) = midi_realtime_message(&bytes) {
            let _ = midi_tx.send(message);
        }
    });

    let samples_dir = default_samples_dir();
    ensure_runtime_dirs(&store_dir, &samples_dir);
    let render_worker = RenderWorker::spawn(HardwareRenderTargets {
        oled,
        seesaw_tx: seesaw_io.command_tx.clone(),
        hdmi: render::hdmi::HdmiFramebuffer::open_from_env(),
    });

    let runtime = runtime_thread::spawn(runtime_thread::RuntimeThreadConfig {
        audio: audio.as_ref().map(AudioManager::service),
        store_dir,
        samples_dir,
        midi_handler,
        usb_midi_out_enabled: usb_config.midi_out_enabled,
        usb_audio_out: usb_config.audio_out,
        midi_rx,
        input_rx: seesaw_io.input_rx,
        encoder_rx: event_rx,
        render_worker,
        early_boot_splash: early_boot_splash_enabled(),
    });
    if runtime.join().is_err() {
        eprintln!("pi runtime thread panicked");
    }
}

fn run_requested_utility() {
    if dsp_profile::profile_requested() {
        std::process::exit(exit_code(dsp_profile::run_dsp_profile().is_ok()));
    }
    if timing_probe::requested() {
        std::process::exit(exit_code(timing_probe::run()));
    }
    if diagnostics::diagnostic_requested() {
        std::process::exit(exit_code(diagnostics::run_pre_hardware_diagnostics()));
    }
    if oled_test::requested() {
        std::process::exit(exit_code(oled_test::run()));
    }
    if hardware_test::noise_requested() {
        std::process::exit(exit_code(hardware_test::run_noise_only()));
    }
    if hardware_test::requested() {
        std::process::exit(exit_code(hardware_test::run()));
    }
}

fn exit_code(success: bool) -> i32 {
    if success {
        0
    } else {
        1
    }
}

fn early_boot_splash_enabled() -> bool {
    std::env::var("OCTESSERA_EARLY_BOOT_SPLASH").as_deref() == Ok("1")
}

fn init_audio(
    output_buffer_frames: Option<u32>,
    audio_out: usb_config::UsbAudioOut,
) -> Option<AudioManager> {
    match AudioManager::new(output_buffer_frames, audio_out) {
        Ok(audio) => {
            println!("Audio ready");
            Some(audio)
        }
        Err(error) => {
            println!("Audio init failed: {error} (continuing without audio)");
            None
        }
    }
}

fn audio_output_buffer_frames_from_default_config(store_dir: &std::path::Path) -> Option<u32> {
    let payload = std::fs::read_to_string(store_dir.join("default.json")).ok()?;
    let payload: serde_json::Value = serde_json::from_str(&payload).ok()?;
    payload
        .get("runtimeConfig")
        .unwrap_or(&payload)
        .get("sound")
        .and_then(|sound| sound.get("audioOutputBufferFrames"))
        .and_then(serde_json::Value::as_u64)
        .map(|value| value as u32)
}

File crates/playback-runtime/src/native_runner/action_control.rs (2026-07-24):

use crate::native_menu::NativeMenuAction;
use crate::protocol::RuntimePlatformEffect;

use super::{
    derive_instrument_name, native_binding_from_spec, parse_sample_action, synth_preset_config,
    NativeAuxBinding, NativeInstrumentSlot, NativeRunner, NativeToast, RuntimeTransportState,
    Value, GRID_HEIGHT,
};

impl NativeRunner {
    pub(super) fn handle_sample_action(
        &mut self,
        action: &str,
    ) -> Result<Option<RuntimePlatformEffect>, String> {
        if action == "factory.load" {
            self.apply_factory_payload()?;
            return Ok(None);
        }
        if action == "sparks.fx.map" {
            let config = self.sparks_fx_selected.clone();
            self.sparks_fx_assign = Some(config.clone());
            self.active_sparks_mode = "fx".into();
            self.display.toast = Some(NativeToast {
                message: format!("Map FX: {}", super::sparks_fx_type(&config)),
                offset: 0,
            });
            return Ok(None);
        }
        if let Some(rest) = action.strip_prefix("sample.assign:") {
            let (instrument_slot, sample_slot, _) = parse_sample_action(rest)?;
            self.sample_assign = Some((instrument_slot, sample_slot));
            self.show_toast(format!("Assign S{}: grid", sample_slot + 1));
            return Ok(None);
        }
        if let Some(rest) = action.strip_prefix("trigger.probability.assign:") {
            if let Ok(layer_index) = rest.parse::<usize>() {
                self.trigger_probability_assign = Some(layer_index.min(GRID_HEIGHT - 1));
                self.show_toast(format!("Trig L{}: grid", layer_index + 1));
            }
            return Ok(None);
        }
        if let Some(rest) = action.strip_prefix("synth.preset:") {
            let mut layers = rest.splitn(2, ':');
            let slot = layers.next().and_then(|value| value.parse::<usize>().ok());
            let preset = layers.next();
            if let (Some(slot), Some(preset)) = (slot, preset) {
                self.load_synth_preset(slot, preset);
            }
            return Ok(None);
        }
        self.handle_sample_browser_action(action)
    }

    pub(super) fn load_synth_preset(&mut self, slot: usize, preset: &str) {
        let Some(instrument) = self.instruments.get_mut(slot) else {
            return;
        };
        let synth_config = synth_preset_config(preset);
        let gain = synth_config
            .get("amp")
            .and_then(|amp| amp.get("gainPct"))
            .and_then(Value::as_u64)
            .unwrap_or(80) as u8;
        instrument.kind = "synth".into();
        if instrument.auto_name {
            instrument.name = derive_instrument_name(slot, "synth");
        }
        instrument.synth_config = synth_config;
        instrument.synth_gain_pct = gain;
        self.display.toast = Some(NativeToast {
            message: format!("Loaded synth {preset}"),
            offset: 0,
        });
        self.mark_config_dirty();
        self.menu.rebuild(self.menu_config());
    }

    pub(super) fn execute_confirmed_action(
        &mut self,
        action: NativeMenuAction,
    ) -> Result<Option<RuntimePlatformEffect>, String> {
        self.execute_menu_action_inner(action, true)
    }

    pub(super) fn execute_menu_action(
        &mut self,
        action: NativeMenuAction,
    ) -> Result<Option<RuntimePlatformEffect>, String> {
        self.execute_menu_action_inner(action, false)
    }

    fn execute_menu_action_inner(
        &mut self,
        action: NativeMenuAction,
        confirmed: bool,
    ) -> Result<Option<RuntimePlatformEffect>, String> {
        if !confirmed {
            if let Some(confirm) = self.confirmation_for_action(&action) {
                self.display.confirm_dialog = Some(confirm);
                return Ok(None);
            }
        }
        match action {
            NativeMenuAction::BehaviorAction(action_type) => {
                self.trigger_behavior_action(action_type)?;
                Ok(None)
            }
            NativeMenuAction::SelectBehavior(behavior_id) => {
                self.select_behavior(&behavior_id)?;
                Ok(None)
            }
            NativeMenuAction::SelectLayerBehavior {
                layer_index,
                behavior_id,
            } => {
                self.select_layer_behavior(layer_index, &behavior_id)?;
                Ok(None)
            }
            NativeMenuAction::NavigateBack => {
                self.menu.back();
                Ok(None)
            }
            NativeMenuAction::PlatformEffect(action_type) => {
                if let Some(name) = action_type.strip_prefix("preset.renamePick:") {
                    self.preset_rename_source = Some(name.into());
                    self.preset_draft_name = name.into();
                    Ok(None)
                } else if action_type == "preset.saveCurrent" && self.current_preset_name.is_none()
                {
                    self.display.toast = Some(NativeToast {
                        message: "No preset loaded".into(),
                        offset: 0,
                    });
                    Ok(None)
                } else if action_type == "midi.panic" {
                    self.display.toast = Some(NativeToast {
                        message: "MIDI panic sent".into(),
                        offset: 0,
                    });
                    Ok(self.platform_effect_for_action(&action_type))
                } else if action_type == "system.controlsHelp" {
                    self.open_controls_help();
                    Ok(None)
                } else if action_type == "system.info" {
                    self.open_system_info();
                    Ok(self.platform_effect_for_action(&action_type))
                } else if action_type == "system.clearAll" {
                    self.clear_patch_state()?;
                    Ok(None)
                } else if action_type == "system.reboot" || action_type == "system.shutdown" {
                    self.display.oled_mode = super::NativeOledMode::Splash;
                    self.display.oled_splash_text = super::OLED_SHUTDOWN_SPLASH_KEY.into();
                    self.display.oled_splash_until = Some(
                        std::time::Instant::now()
                            + std::time::Duration::from_millis(
                                super::OLED_SHUTDOWN_SPLASH_FAILSAFE_MS,
                            ),
                    );
                    if action_type == "system.reboot" {
                        self.show_toast("Octessera is rebooting");
                    } else {
                        self.show_toast("Octessera is shutting down");
                    }
                    self.outbox
                        .push_platform_effect(if action_type == "system.reboot" {
                            RuntimePlatformEffect::Reboot
                        } else {
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

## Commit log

2026-04-30 Add Tauri native audio bridge and stabilize CI desktop smoke build
    [main.rs]
2026-04-30 Stabilize CI pipeline and tighten native trigger mapping behavior
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2026-05-02 Migrate platform to 8x8 hardware profile and add logic tests
    Align runtime, simulator, and docs with the 8x8 grid and updated hardware contracts while adding a non-UI platform-core test suite to lock interpretation, mapping, menu, and scan timing behavior.
    [PCB.stl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]
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2026-05-03 Polish simulator layout, controls, and transport visuals
    Refine the hardware-parity panel layout, fix menu list rendering and selection highlighting, add Up/Down main-encoder mappings, keep Shift momentary, and tune the initial desktop window size for a more compact default launch.
2026-05-03 Refine OLED menu density and simulator display polish
    Tighten OLED line spacing, remove empty spacer rows, expand menu viewport usage, and align simulator display behavior with compact list-style navigation and updated pause/icon presentation.
2026-05-03 Tune simulator control panel spacing and encoder feedback
    Add visible 8-tick encoder ring feedback, tighten button stack sizing/alignment, and refine control-panel spacing so the hardware-style layout is clearer and more balanced.
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2026-05-03 Refactor modulation model to additive axis lanes
    Introduce shared pitch bounds/anchor settings, convert X/Y modulation to enabled lane groups, add signed pitch steps with additive axis behavior, and update scan-unit controls plus OLED/menu formatting and tests. Also shorten transport pulse flash timing for better BPM readability.
2026-05-03 Fix CI typecheck and test glob compatibility
    Replace fragile DeviceInput id indexed types in desktop UI with explicit encoder ids for strict typecheck compatibility, and update package test scripts to use cross-platform test globs that run reliably on GitHub Actions Linux shells.
2026-05-03 Harden runtime timing with high-res scheduler and lookahead queue
    Decouple transport stepping from UI cadence by using performance.now-based elapsed timing, pulse-accurate accumulator stepping, capped catch-up windows, and a timestamped event lookahead queue for output dispatch to improve MIDI-readiness and reduce jitter.
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2026-05-04 Midi full implementation, cleanup
    [cellSymphony-B_Cu.gbr, cellSymphony-B_Mask.gbr, cellSymphony-B_Paste.gbr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]
2026-05-04 Fix GitHub CI build and clean up obsolete code/docs
    - Fix CI: remove broken artifact_validation job, fix fixture test path, fix step names
    - Remove obsolete docs: grid-interpretation-decoupling-plan, cleanup-roadmap, sprint-1-backlog (→ archive)
    - Remove tools/midi-smoketest (replaced by packages/midi-headless-runner)
    - Fix Cargo workspace: remove midi-smoketest reference
    - Remove Web MIDI (webMidi.ts deleted, TauriMidiService now handles in+out)
    - Move Audio menu under System in platform-core
    - Remove VITE_MIDI_SMOKETEST smoketest block from simulatorRuntime
    - Add MIDI menu port-list request tests in platform-core
    - Fix test:fixtures to check existing docs/menu-and-controls-spec.md
    [main.rs]
2026-05-04 Fix S-button LED to match OLED flash; fix startup stopped state
    - Fix S-button LED (simulatorRuntime.ts):
    - Remove local transportFlash/transportFlashUntilMs variables
    - Remove applyBeatFlash() function (core state handles flash timing)
    - snapshotFromState() now reads next.system.transportFlash (core state)
    - Button LED and OLED now use same source of truth
    - Remove buggy stopLatched = false block in button_s handler
    - Fix fresh startup / STOP->PLAY measure flash (platform-core/index.ts):
    - Initial state: stopLatched = true (boot in stopped state, not paused)
    - First S press now triggers measure reset + red flash (isStopToPlay check)
    - Covers both SHIFT+S->S and fresh startu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
2026-05-04 Clean up obsolete documentation
    - Delete docs/adr/ (ADRs 1-6 superseded by current code)
    - Delete docs/experiments/ (superseded by current code)
    - Delete docs/archive/ (sprint-1-backlog already merged)
    - Delete docs/simulator-hardware-parity-plan.md (superseded by menu-and-controls-spec.md)
    - Delete docs/matrix-pipeline-architecture.md (superseded by current code)
    - Delete docs/hardware-bom-and-io-plan.md (outdated hardware plan)
    - Delete docs/architecture-modularity.md (superseded by runtime-boundaries.md)
    - Update docs/runtime-boundaries.md: reflect Tauri-only MIDI, correct paths, clarify output adapters
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2026-05-04 Merge Current MVP Scope into Status & roadmap section
    - Replace duplicate Current MVP Scope + Status & roadmap with single Status & roadmap
    - Subsections: Done/Functional, In Progress, Not Implemented Yet, Future Roadmap
    - Remove duplicate bottom section
2026-05-04 Add per-section OLED colors and fix menu rendering
    - Add pastel color scheme (green/blue/lavender/sepia) for menu sections
    - Use non-sepia logo on startup, keep sepia for sleep transition
    - Fix selected item rendering to use section color as background (black text on color)
    - Add DisplayFrame colors property for OLED rendering pipeline
    - Fix menu item color propagation through submenus and sub-submenus
    - Fix spacer handling and line/color alignment issues
    - Add L1/L2/L3 section labels (Life/Sense/Voice) with proper coloring
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2026-05-05 Fix HAL crate compilation errors and update Pi-Zero app
    - Fix spidev API: use SpidevOptions instead of Settings
    - Fix nix ioctl: enable ioctl feature, use libc for I2C_SLAVE
    - Fix rppal API: use Trigger::FallingEdge instead of Event::Falling
    - Add AsRawFd import for File descriptors
    - Fix type mismatches in neotrellis (usize vs u8)
    - Remove rodio from HAL (belongs in Pi app)
    - Update Pi-Zero app to use HAL correctly
    - Add .cargo/config.toml for ARM cross-compilation linker
    - HAL crate now builds for armv7-unknown-linux-gnueabihf target
    [encoder_gpio.rs, main.rs]
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2026-05-05 Fix CI: Run Rust checks on ubuntu-latest instead of windows-latest
    - --all-features includes pi-zero which requires Linux-only crates (rppal, spidev, nix)
    - Windows runner cannot compile these crates
    - Switch to ubuntu-latest for rust_fmt, rust_lint, rust_test jobs
2026-05-05 Fix CI: exclude pi-zero from clippy/test, add Pi build check
    - Remove --all-features from clippy/test (causes Linux-only crate errors)
    - Exclude cellsymphony-pi from clippy and test jobs
    - Add pi_zero_build job to verify ARM build on Linux
    - Remove rppal from pi-zero app deps (already in hal)
2026-05-05 Pi-Zero app: working base build without audio/MIDI deps
    - Remove rodio/cpal from HAL (caused cross-compilation ALSA issues)
    - Simplify i2s_dac.rs to stub (actual audio will use Pi-native libs)
    - Remove midir temporarily (needs ALSA cross-compile setup)
    - Pi binary now builds successfully for armv7-unknown-linux-gnueabihf
    - Hardware init works: encoders, I2C, OLED, grid scan
    - Audio/MIDI to be added once Pi deployment setup is ready
    [main.rs]
2026-05-05 Pi-Zero: audio/MIDI ready for native compilation
    - Update main.rs with AudioManager (rodio) and MIDI input (midir)
    - These work when compiled natively on Pi (ALSA available)
    - Cross-compilation from Windows fails (alsa-sys needs ALSA libs)
    - Add tools/deploy-pi.sh for one-step Pi deployment
    - Add docs/PI_DEPLOYMENT.md with native/cross-compile options
    - Current Windows build (without audio/MIDI deps) still works
    - Pi deployment: native compile on Pi, enable I2S, auto-start via systemd
    [main.rs]
2026-05-05 CI: add Pi app build via Docker cross-compilation
    - Split Pi build into HAL check (quick) and full app build
    - pi_zero_hal_build: builds cellsymphony-hal with pi-zero feature
    - pi_zero_app_build: uses cross Docker container with ALSA libs
    - Docker container ghcr.io/cross-rs/cross/armv7-unknown-linux-gnueabihf has:
    - ARM cross-compiler
    - ALSA development libraries for target
    - This builds rodio/midir deps that previously failed
2026-05-05 CI: custom Docker image with ALSA for Pi build
    - Create Dockerfile.pi-zero with Ubuntu 22.04 + ARM cross-compiler
    - Install libasound2-dev:armhf for ALSA cross-compilation
    - Set PKG_CONFIG_PATH for ARM target
    - Update CI to build custom image then use cross command
    - Fixes alsa-sys pkg-config error during rodio/midir build
2026-05-05 CI: fix Pi build with cross + custom Docker image
    - Fix Dockerfile.pi-zero syntax (FROM ghcr.io/cross-rs/cross/armv7-unknown-linux-gnueabihf:main)
    - Create Cross.toml to tell cross to use custom image
    - Dockerfile installs libasound2-dev:armhf for ALSA cross-compilation
    - Set PKG_CONFIG_PATH for ARM target (fixes alsa-sys pkg-config error)
    - cross command now uses custom image automatically via Cross.toml
2026-05-05 Fix Send trait error: use channel for MIDI messages instead of calling audio in callback
    [main.rs]
2026-05-05 Fix PowerShell syntax: wrap $installer.FullName in $() for proper evaluation
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2026-05-16 Add contextual menu help with strict TSV coverage lint
    [menu-help-texts.tsv]
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2026-05-18 Fix sticky Fn/Shift state and expand menu help coverage
    [menu-help-texts.tsv]
2026-05-18 Improve enum help rules and rename scan mode display
    [menu-help-texts.tsv]
2026-05-18 Expand behavior and synth help descriptions
    [menu-help-texts.tsv]
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2026-05-18 Add per-slot synth preset loading and improve default/runtime state handling
    [menu-help-texts.tsv]
2026-05-19 Fix factory reset behavior and update note-mapping defaults
    Make factory reset always restore the canonical life behavior instead of preserving the currently selected one. Update factory pitch defaults to C4 start with x-step 0/y-step 1, remove conflicting default migration, and align docs/tests with the new baseline.
2026-05-20 Add part-scoped L1/L2 flow and type-aware global voice slots
    Move Life/Sense editing onto active part paths while keeping Fn+left-column as fast layer select with Fn-held LED indicators. Extend global instrument slots to synth/sample/midi with type-specific co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
    [menu-help-texts.tsv]
2026-05-20 Enforce 500 LOC cap and relocate menu help resource
    [menu-help-texts.tsv]
2026-05-20 Fix menu help matching for instrument labels
    [menu-help-texts.tsv]
2026-05-20 Fix platform-core types for sample browse and save state
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2026-05-20 Refactor instrument slot count to capability-driven 8
    [menu-help-texts.tsv]
2026-05-21 Add load-aware global voice stealing modes
    [menu-help-texts.tsv]
2026-05-21 Add busCount to platform capabilities
    [menu-help-texts.tsv]
2026-05-21 Add FX bus slot effect config schema
    [menu-help-texts.tsv]
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2026-05-21 Fix FX parameter defaults
    [menu-help-texts.tsv]
2026-05-21 Route sample instruments through realtime engine mixer
    - Added SampleBuffer, SampleSlotConfig, SampleBankConfig types
    - Sample voices render into slot_out[] before route/bus/FX processing
    - Desktop decodes WAVs outside audio callback, caches in sample_cache
    - Removed musical sample bypass sink; sample note_on sends EngineEvent::NoteOn
    - Fixed duck gain reduction formula for audible attenuation at normal levels
    - Added engine-level regression tests for sample bus FX and duck
    - Updated docs with audio routing contract and guardrails
    - Updated menu-help-texts.tsv for synth+sample coverage
    [menu-help-texts.tsv]
2026-05-22 Add compressor + EQ FX bus effects, rename Bus to FX Bus
    Effects:
    - Compressor: envelope follower, threshold/ratio/attack/release/makeup/mix
    - EQ: 3-band with low shelf, peaking mid, high shelf via biquad filters
    Rename:
    - Canonical route IDs: bus_N -> fx_bus_N (old bus_N accepted on load)
    - UI labels: Bus N -> FX Bus N, Bus Slot -> FX Slot
    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
    [menu-help-texts.tsv]
2026-05-22 Add grid_release, none/keys behaviors, and interpretInputTransitions
    - Add grid_release variant to DeviceInput in device-contracts
    - Add interpretInputTransitions flag to BehaviorEngine interface
    - Scaffold behaviors-none (no-op) and behaviors-keys (grid press/release)
    - Implement input transition pipeline in inputRouter.ts
    - Register none and keys in platform-core
    - Emit grid_release from desktop simulator on mouseup
    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
    [menu-help-texts.tsv]
2026-05-22 Lowercase all selectable pluggable names
    - Behavior display names: Sequencer→sequencer, Game of Life→game of life, etc.
    - Synth preset labels: Init→init, Soft Pad→soft pad, etc.
    - FX effect group labels: Duck→duck, Delay→delay, Compressor→compressor, EQ→eq, etc.
    - Updated tests, docs, and TSV help entries to match
    [menu-help-texts.tsv]
2026-05-24 Auto-save cooldown, coalesced audio config, toast helper, aux stale binding, naming migration, geometric bars, numeric display mode, FX state preservation, and backlog document
    - Auto-save cooldown: deferred 2s trailing writes for config edits, immediate for explicit saves
    - Coalesced audio config sender: signature-gated setInstruments to avoid unnecessary IPC
    - Toast helper: centralized makeToast() with scrolling support on OLED
    - Aux stale binding: scoped 'not active' toasts on inactive aux use (no proactive unbinding)
    - Naming migration: autoName/name replaces nameMode/customName across instruments, buses, parts
    - Geometric bar rendering: smooth fillRect bars with numChars-based position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
    [menu-help-texts.tsv]
2026-05-26 Add L4 touch performance layer
    [menu-help-texts.tsv]
2026-05-26 Add Touch FX mapping and fix navigation
    [menu-help-texts.tsv]
2026-05-26 Fix Touch grid navigation, mixer volume, FX cap, and autosave
    [menu-help-texts.tsv]
2026-05-27 Fix cargo fmt formatting in engine.rs and tests.rs
    [menu-help-texts.tsv]
2026-05-27 Fix missing volume field in Pi app InstrumentMixerConfig init
    [main.rs]
2026-05-28 Touch: aux mapping overlay, FX targets, remove Playback
    [menu-help-texts.tsv]
2026-05-31 feat(platform-core): auto-save 'S' flash indicator; replace stateEnabled with inputEventsWhilePaused
    - Add autoSaveFlash/autoSaveFlashUntilMs to SystemState, initialized in initialState
    - Tick decay clears autoSaveFlash after 500ms via Date.now().equals(nowMs())
    - Render 'S' glyph at OLED top-right in splash and normal modes (oledRender)
    - Wire autoSaveFlash through simulatorFrameBuilder to desktop runtime
    - Add isAuto? flag to save_default_result StoreResult
    - applyStoreResult: isAuto=true => flash only, no toast; manual save => flash + toast
    - Deferrd save path now routes through applyStoreResult in flushPendingDefaultSave
    - Replace deprecated stateEnabled with inputEventsWhilePaused acros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
    [menu-help-texts.tsv]
2026-05-31 fix: dedup behavior reinit in inputRouter, centralize aux encoder helpers, fix spread syntax
2026-06-01 feat: replace shift double-tap with Fn+Shift for sample column assignment
    - Shift alone selects the whole row during sample assignment
    - Fn+Shift selects the whole column (was Shift double-tap)
    - Remove sampleAssignLastPress state and SAMPLE_ASSIGN_REPEAT_WINDOW_MS
    - Update docs, help text, and test to match
    [menu-help-texts.tsv]
2026-06-01 WIP: Preparing for Shift+Fn modifier implementation
    [PCB.stl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]
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2026-06-02 Merge: combined modifier, sample browser, touch page, auto-map prefix fixes
    - Combined modifier: FN+SHIFT gating and LED rendering
    - Sample browser: fix instrument path regex, remove loading flag, add tests
    - Touch page: fix row selection, add FX momentary mode
    - Auto-map: fix prefix display when cursor highlights a subgroup
    - Keyboard adapter: edge handling improvements
    - Clean up scratch/debug files
    [menu-help-texts.tsv]
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2026-06-03 Panning improvements, UI cleanup, device/simulator parity
    [menu-help-texts.tsv]
2026-06-03 Split inputRouter and stateHelpers to fix CI quality lint; fix param-map.test.ts type errors
    - Split inputRouter.ts (528->~270 lines) into 6 files:
    inputModifier.ts, inputConfirm.ts, inputMIDI.ts, inputGrid.ts,
    inputAux.ts (thin dispatcher remains)
    - Split stateHelpers.ts (517->~220 lines) into 3 files:
    paramAccess.ts, behaviorState.ts (stateHelpers.ts keeps 3 exports)
    - Add pre-push hook running lint/typecheck/format/cargo checks
    - Fix param-map.test.ts: use applyModulation API, inline assertions,
    ambient describe/test decls (no @types/node dependency)
    - Fix inputAux.ts DeviceInput type guard
    - Update index.ts imports for split files
    - Update features-runtime.test.ts import path
    - R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
2026-06-03 Wire shift+aux press to assignAuxEncoder; add pnpm test to pre-push hook
    - Add shift+aux encoder press handler in inputRouter.ts that calls
    assignAuxEncoder for binding/unbinding current menu parameter
    - Fix 4 pre-existing test failures in features-aux.test.ts that
    relied on this missing wiring
    - Add pnpm test step to .githooks/pre-push (all 180 tests pass)
2026-06-03 feat: flatten instrument and effect groups via flat: true on MenuNode
    Remove intermediate submenu steps for Synth, Sampler, Note Settings,
    and all 13 effect groups by adding flat property to group nodes.
    visibleChildren flatMaps flat groups; deriveGroupKey accepts state
    for sampler detection. Update tests and menu-help-texts.tsv paths.
    [menu-help-texts.tsv]
2026-06-03 feat: filter and flatten L4: Dance menu by active touchMode
    Make L4: Dance children a function that shows only page-relevant items:
    Dance Page and BPM always first, then FX Page or Trigger Gate (flat: true)
    when the corresponding touchMode is active. Hide irrelevant page groups
    when on mix/pan/none pages. Cursor re-maps to edited enum after tree
    reorder. Rename 'Edit Target' to 'Target Part' in Trigger Gate.
    [menu-help-texts.tsv]
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2026-06-04 purge stale artifacts: .bak, .orig, cargo artifacts, .qwen/skills/, PCB.stl, Mouser cart PDF, gerber.zip
    - git rm inputRouter.ts.bak (backup)
    - git rm .cargo-ok, .cargo_vcs_info.json, Cargo.toml.orig (cargo artifacts)
    - git rm hardware/KiCAD/gerber/gerber.zip (redundant)
    - git rm .qwen/settings.json.orig (backup)
    - git rm -r .qwen/skills/ (17 SKILL.md files — AI dev history)
    - git rm hardware/KiCAD/PCB.stl, hardware/Mouser Cart with Components.pdf (binaries)
    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
    [PCB.stl]
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2026-06-05 audio: add global fx master chain
    [menu-help-texts.tsv]
2026-06-05 platform-core: persist dance mode state
    [menu-help-texts.tsv]
2026-06-05 platform-core: fix dance help TSV rows
    [menu-help-texts.tsv]
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2026-06-18 hardware: add new PCB revision with KiCAD libs and reports
    [cellSymphony-B_Cu.gbr, cellSymphony-B_Mask.gbr, cellSymphony-B_Paste.gbr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]
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2026-06-22 fix: stabilize deferred menu apply timing
    [construction.rs]
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2026-06-23 fix: satisfy sample favourites clippy
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2026-06-25 fix: improve menu display and autosave responsiveness
    [action_control.rs, construction.rs]
2026-06-25 fix: defer native text menu applies
    [config.rs]
2026-06-26 perf: avoid Pi snapshot clone on render
    [main.rs]
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2026-06-27 fix: sanitize saved default payload
    [config.rs]
2026-06-27 fix: prioritize playback during structural edits
    [main.rs]
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2026-06-28 fix: keep looper mode changes live-safe
    [menu-help-texts.tsv]
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2026-06-28 ci: fix pi image stage file paths
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2026-07-01 fix: harden pi hardware bring-up
    [hardware_fault.rs, hardware_init.rs, main.rs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]
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2026-07-04 fix pi hardware input and menu edit performance
    [construction.rs, encoder_gpio.rs, hardware_init.rs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]
2026-07-04 fix desktop audio command plumbing
    [main_runtime_loop.rs]
2026-07-04 fix pi transport and hardware UI polish
    [menu-help-texts.tsv]
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2026-07-04 fix hardware release and menu display polish
    [construction.rs]
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2026-07-05 stabilize pi playback timing
    [menu-help-texts.tsv]
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2026-07-05 fix timing probe clippy lint
2026-07-05 fix pi timing probe clippy lint
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2026-07-05 add reboot system action
    [menu-help-texts.tsv]
2026-07-05 prompt to reboot after buffer edit
    [construction.rs]
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2026-07-06 fix wake, saves, and display controls
    [menu-help-texts.tsv]
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2026-07-09 Fix enclosure artifacts and 3MF generation
    [case_bottom_plate_cadquery.3mf, case_top_two_level_branded_multicolor.3mf, case_top_two_level_cadquery.stl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]
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2026-07-12 Fix dynamic menus samples and hardware fit
    [friction_insert_expanding_plug_flat_sides.3mf, friction_insert_spreading_pin_headed.3mf, friction_insert_spreading_pin_headed.step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]
2026-07-12 Fix Pi hardware fault clippy order
    [hardware_fault.rs]
2026-07-13 Add USB SD transfer and DSP slot extraction
    [friction_insert_expanding_plug_flat_sides.3mf, friction_insert_expanding_plug_flat_sides.step, friction_insert_expanding_plug_flat_sides.stl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]
2026-07-13 Fix layer-scoped Build behavior menus
    [action_control.rs, config.rs, construction.rs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]
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2026-07-15 Fix Play page mixer controls
    [sparks_control.rs]
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2026-07-17 Revert "Tune NeoKey panel alignment"
    This reverts commit 3bfa92f6f6a57f965a06af47d983c1d65e4b4b05.
    [case_top_two_level_cadquery.stl, case_top_two_level_multicolor.3mf]
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
